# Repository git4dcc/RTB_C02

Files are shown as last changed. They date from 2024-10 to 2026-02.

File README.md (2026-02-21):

# RTB_C02



My C02 module is designed to trace DCC Railcom traffic for decoder debugging and development purposes. In particular the Railcom capture is an important feature and helps to validate if a decoders is RCN-217 compliant. The C02 uses the Vt100 terminal emulation control codes for its user interface. Therefore a VT100 capeable terminal program is a must (e.g. putty, teraterm). The USB interface is galvanically isolated from the DCC track potential.

<details>
<summary>User Guides</summary>

- [User Guide - DE](https://rtb4dcc.de/DPM_User_Guide_de)<br>
- User Guide - EN

</details>

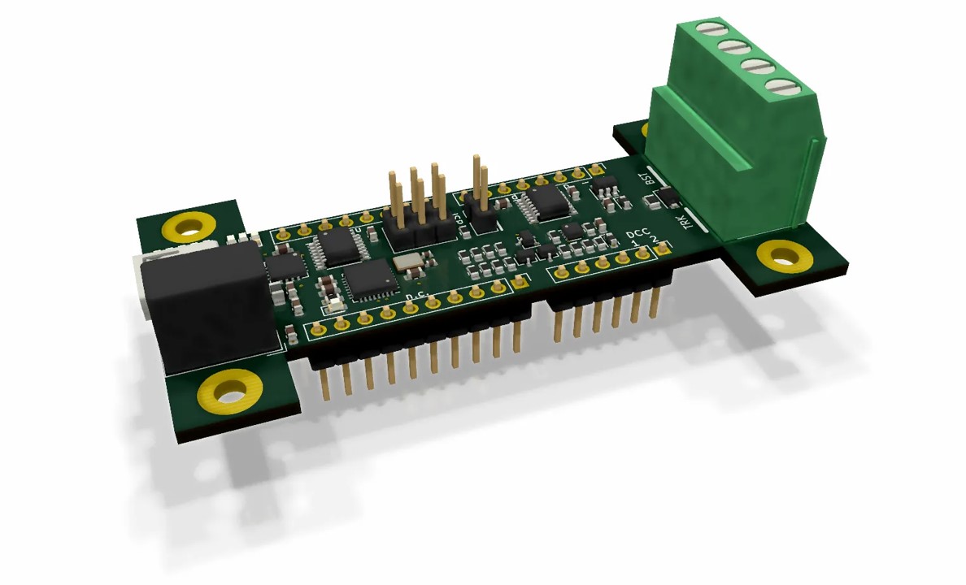
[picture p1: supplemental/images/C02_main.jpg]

<br>

# Hardware
My current PCB layout uses SMD footprints with 0.5mm pitch and mostly 0603 but some 0402 parts. Reflow soldering is my recommendation, but with some experience handsoldering may also be possible.

## PCB
- 4-layer PCB, FR4, 1.6mm
- CPU: mega328pb
- USB: FT232x (Mini-B)
- DC/DC: NME0505SC (or compatible)

## Kicad
[Schematic](doc/C02_schematic.pdf) | [Layout](doc/C02_layout.pdf) | [Gerber](gerber/)

<details>
<summary>Dependency</summary>
<br>
  
:yellow_circle: Requires my Kicad project library [RTB_SamacSys](/../../../../git4dcc/RTB_SamacSys) in the same directory tree.

</details>

## Firmware
Filename structure: { **pcb** }{ **code** }{ **version** }.hex

Example: **C02F0001**.hex

| | Description |
| --- | --- |
| **pcb** | Name of matching hardware (**C02**) |
| **code** | Type of code contained (**R**=rom, **B**=bootloader, **F**=flash, **U**=bld update, **P**=UPDI/SPI factory code) |
| **version** | Release version (**####**) |

## ISP
The fuse settings as well as the P-code (C02Pxxxx.hex) has to be installed by using the ISP.<br>

<details>
<summary>Details</summary>
<br>

> **CAUTION:** Before connecting the ISP, the jumper next to the ISP 6-pin interface must be closed (yellow jumper on picture).

<br>
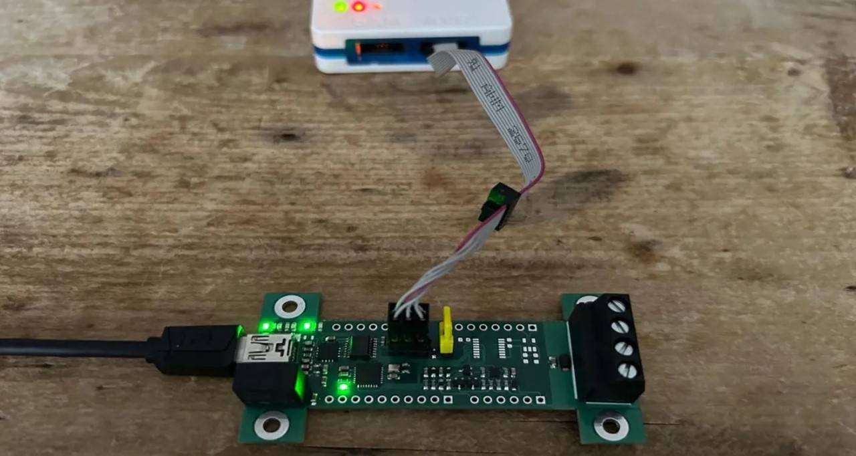
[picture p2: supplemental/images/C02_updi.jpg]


| Fuses Setting | Bootloader Install |
| --- | --- |
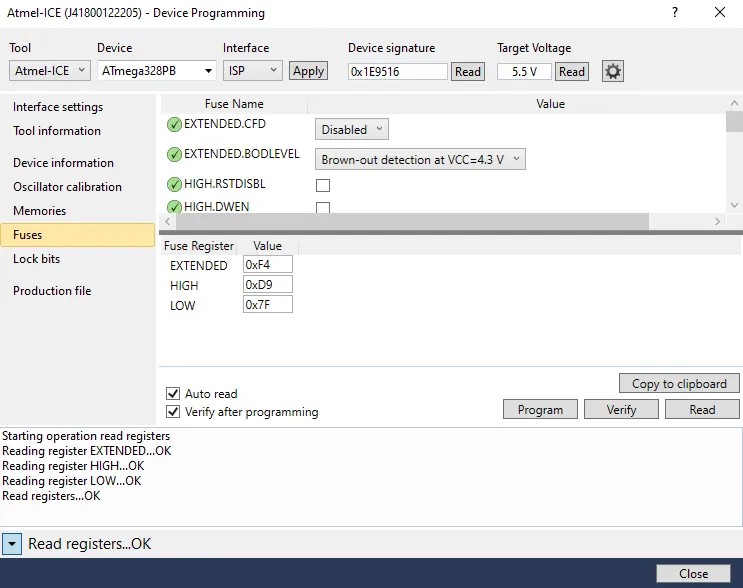
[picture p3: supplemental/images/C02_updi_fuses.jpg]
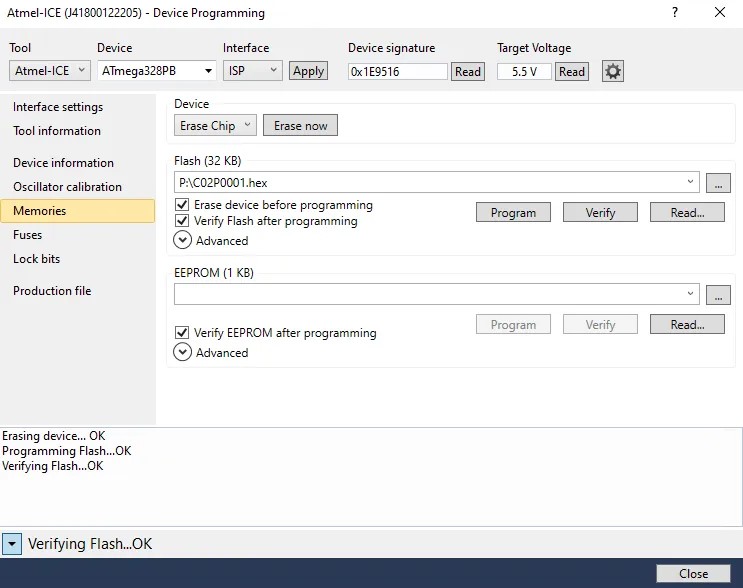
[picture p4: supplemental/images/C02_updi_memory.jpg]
|||

</details>

## Bootloader
Subsequent main code updates can be done via uploading the new firmware (C02Fxxxx.hex) file to the bootloader console prompt.<br>

<details>
<summary>Details</summary>

- press F1 to switch to console screen
- press ^b (ctrl-b) to enter bootloader
- upload the firmware file (C02Fxxxx.hex)
- press x to exit the bootloader

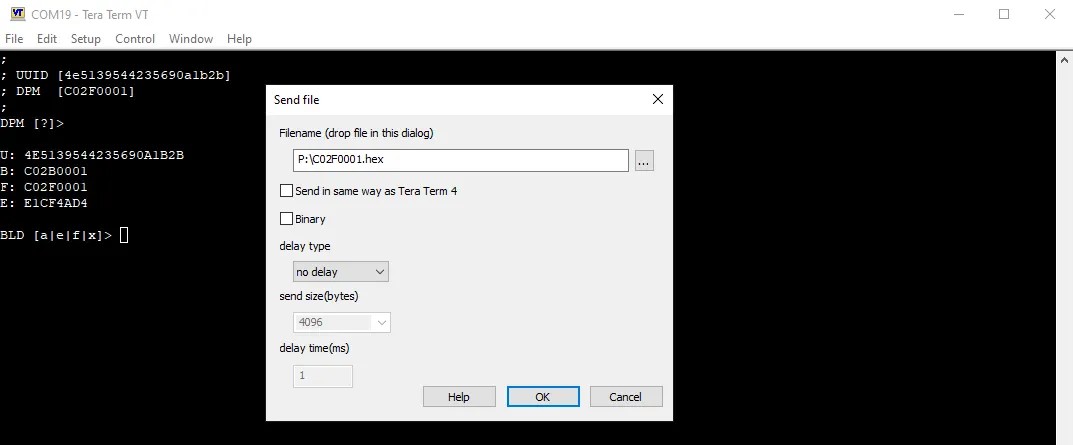
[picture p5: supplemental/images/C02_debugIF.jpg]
  

</details>

# Software
Operating the C02 is within the terminal window.
## Terminal screens
Below some example screens of the different functional sections. The screens (called aspects) can be switched by pressing F1-F7.
All screens are updated in real-time speed, ensuring always up-to-date information shown.

| Aspect | Example |
| --- | --- |
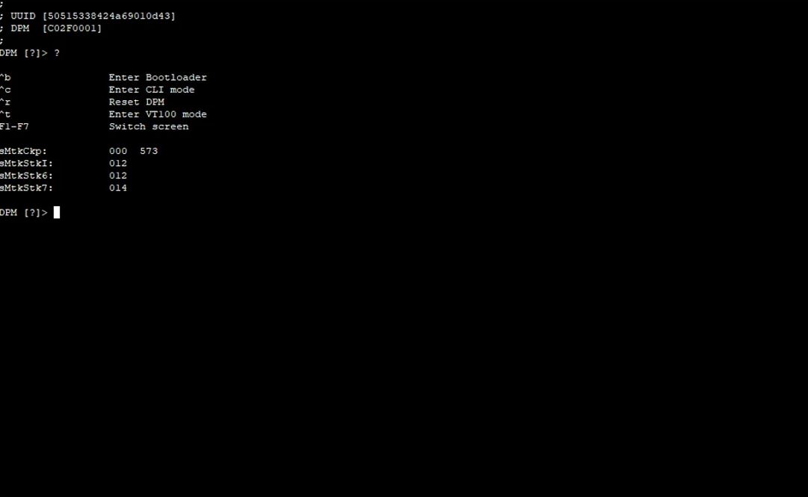
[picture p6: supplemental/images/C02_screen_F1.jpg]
| **F1:** Console prompt. |  |
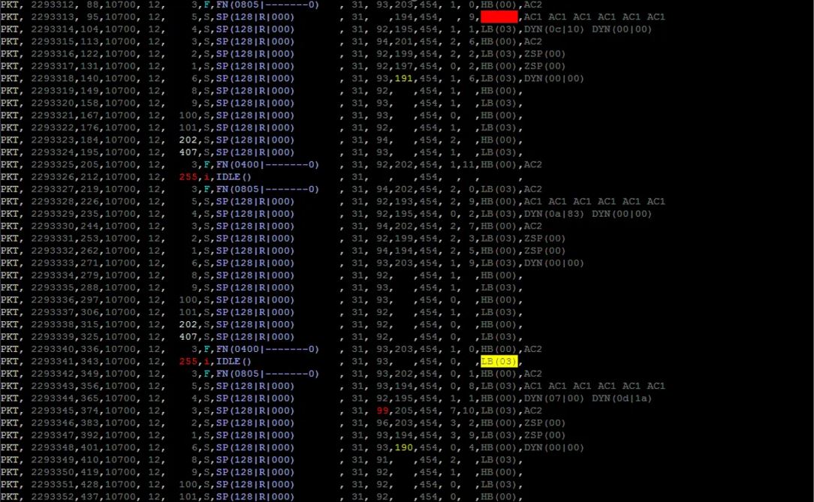
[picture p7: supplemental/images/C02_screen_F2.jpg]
| **F2:** DCC/Railcom line by line real-time trace. |  |
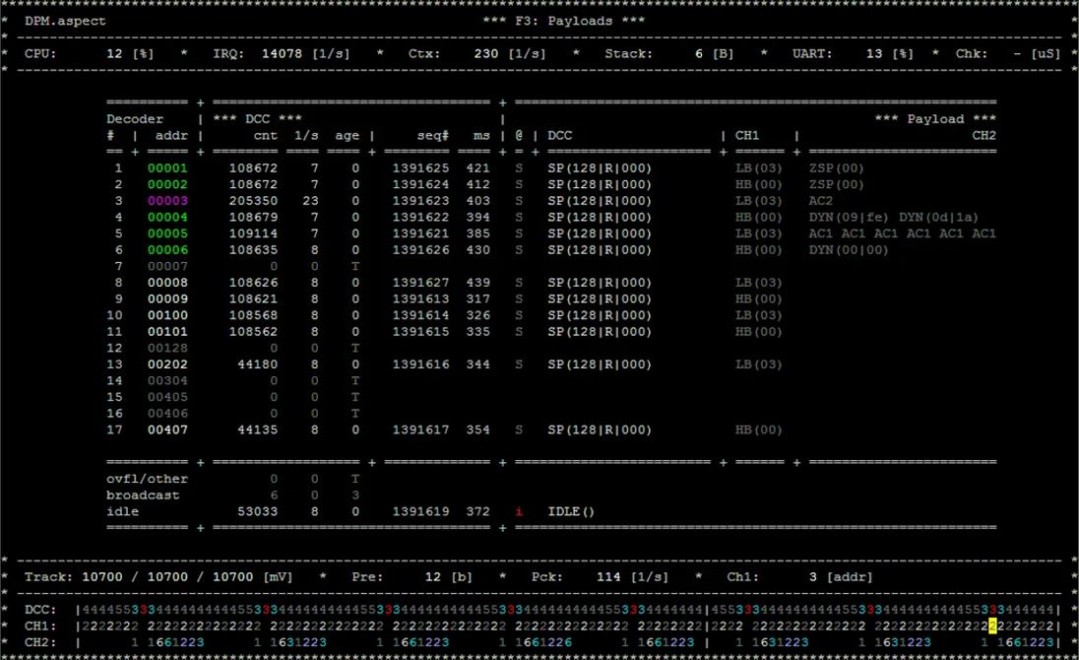
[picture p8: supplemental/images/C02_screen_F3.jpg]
| **F3:** DCC/Railcom decoder payload |  |
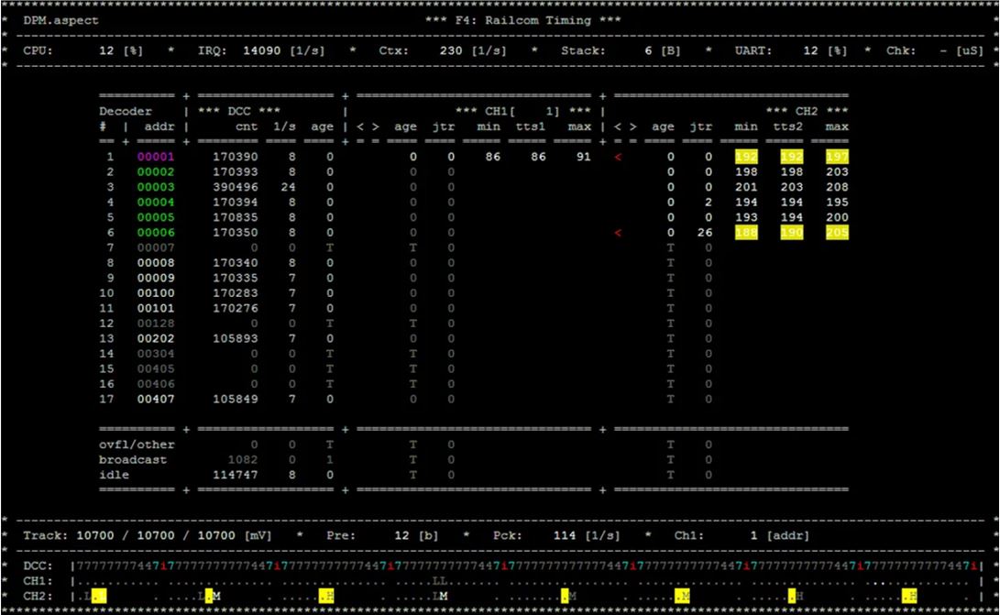
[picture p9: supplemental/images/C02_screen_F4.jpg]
| **F4:** DCC/Railcom timing<br> |  |
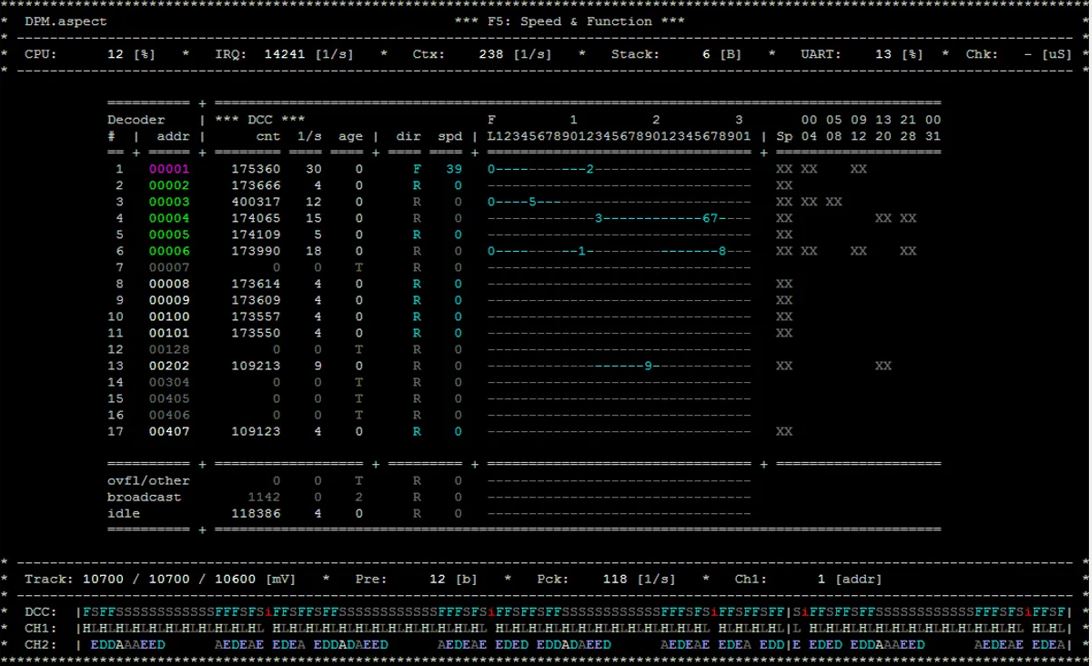
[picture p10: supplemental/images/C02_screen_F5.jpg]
| **F5:** DCC command set |  |
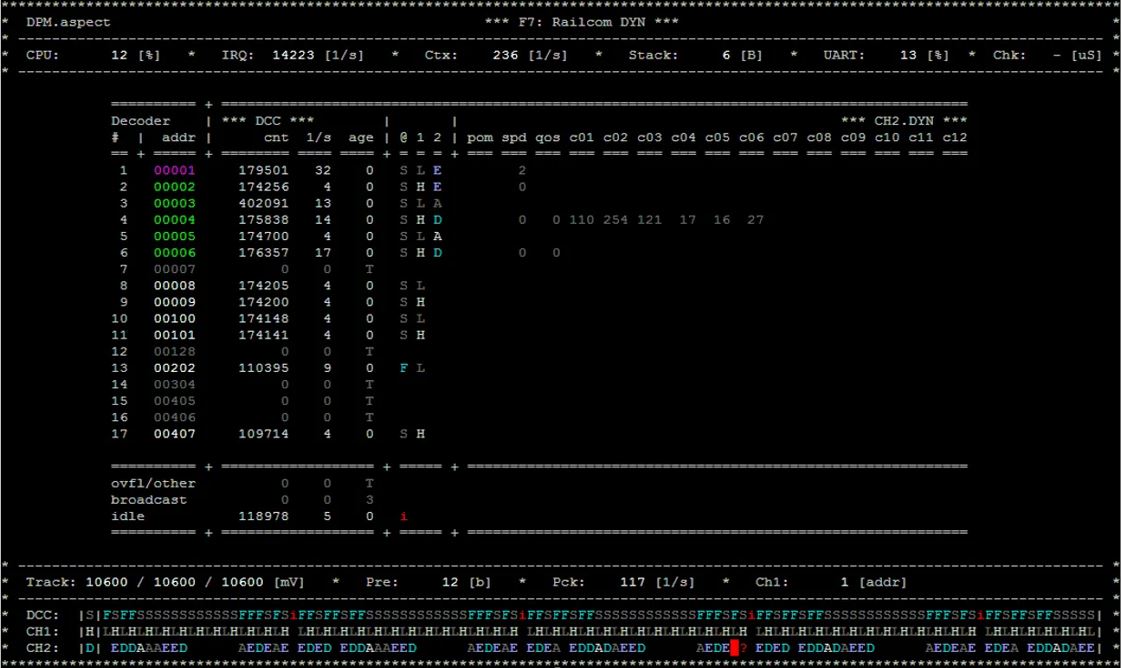
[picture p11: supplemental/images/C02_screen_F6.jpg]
| **F6:** Railcom response set |  |

# Images
This is how the PCB looks like.<br><br>
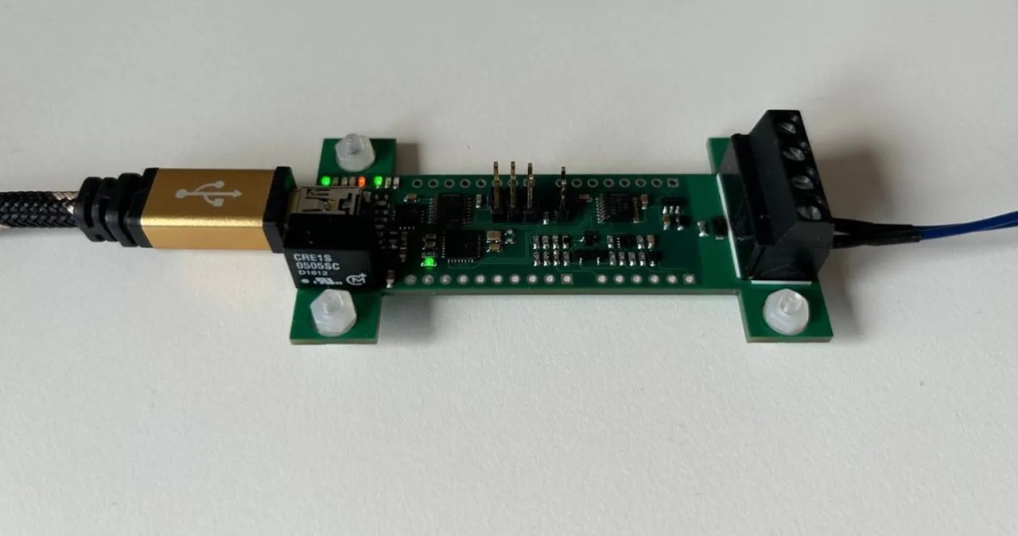
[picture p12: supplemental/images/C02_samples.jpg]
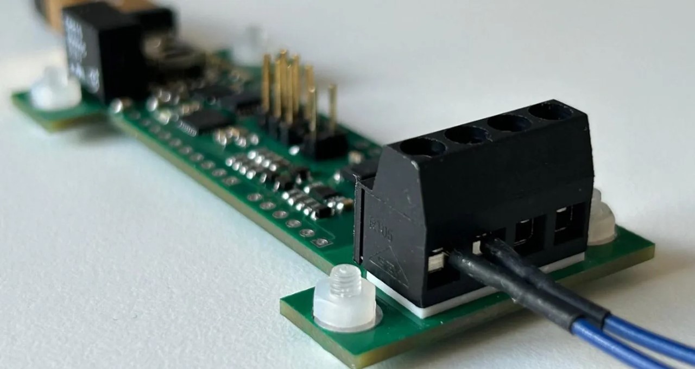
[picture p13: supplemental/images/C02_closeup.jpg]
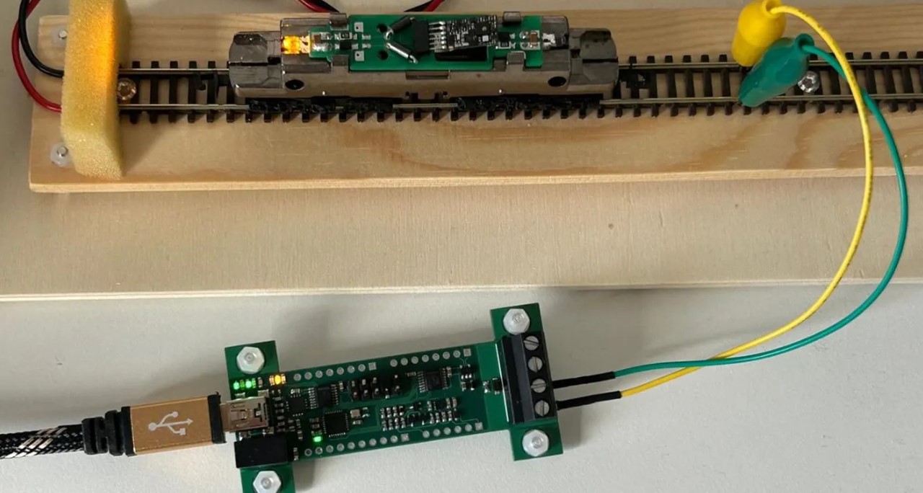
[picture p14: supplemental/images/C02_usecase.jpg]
    

# YouTube
Some short videos to see the DCC/Railcom logger in action.<br><br>
[](https://youtu.be/7zXp4IKSk08)  [](https://youtu.be/JmhkPcqBb-c)

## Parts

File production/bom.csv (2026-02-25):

Designator | Footprint | Quantity | Value | LCSC Part #
C1, C10, C16, C17, C18, C19, C9 | 0603 | 7 | 1u | C15849
C11, C22, C5, C7 | 0603 | 4 | 100n | C14663
C12, C13 | 0402 | 2 | 8p | C32949
C14, C15 | 0603 | 2 | 47p | C1671
C2, C6, C8 | 0603 | 3 | 10u/25V | C96446
D1 | 0603 | 1 | D_Schottky
D10, D19 | D_SMA | 2 | SSA33L | C435944
D11, D12, D8 | 0603 | 3 | LED_grn | C2289
D13 | 0603 | 1 | Hbt(grn) | C2289
D14 | 0603 | 1 | INF(ylw) | C2287
D15 | 0603 | 1 | ACK(blu) | C2288
D16 | 0603 | 1 | LED(grn) | C2289
D17, D18 | 0603 | 2 | LED_red | C125099
D2 | 0603 | 1 | D_Schottky | C143804
D3, D4 | SOT-323_SC-70 | 2 | BAT54S | C78606
D5 | SOT-323_SC-70 | 1 | BAT54A | C78261
J1 | USB_Micro-B_Reichelt_BWM_SMD | 1 | USB_B_Mini | C2688795
J10, J7, J8, J9 | MountingHole_3.2mm_M3_Pad | 4 | Conn_01x01
J11 | PinHeader_2x03_P2.54mm_Vertical | 1 | ISP
J12 | PinHeader_1x02_P2.54mm_Vertical | 1 | Conn_01x02
J2 | PinHeader_1x10_P2.54mm_Vertical | 1 | Conn_01x10_Male
J3 | PinHeader_1x06_P2.54mm_Vertical | 1 | Conn_01x06_Male
J4, J5 | PinHeader_1x08_P2.54mm_Vertical | 2 | Conn_01x08_Male
J6 | TerminalBlock_RND_205-00003_1x04_P5.00mm_Horizontal | 1 | Screw_Terminal_01x04
L1 | 0805 | 1 | Ferrite_Bead | C1017
R1 | 0805 | 1 | 220 | C17557
R10, R12, R33, R7 | 0603 | 4 | 100k | C25803
R11, R9 | 0603 | 2 | 33k | C4216
R13 | 0603 | 1 | 220k | C22961
R14, R32 | 0603 | 2 | 10k | C25804
R15, R22, R23, R24, R25, R26, R28, R29, R30, R31 | 0603 | 10 | 4.7k | C23162
R16, R20 | 0603 | 2 | 27 | C23345
R19 | 0603 | 1 | 3.3k | C22978
R21 | 0603 | 1 | 10 | C22859
R4, R5, R6, R8 | 0603 | 4 | 1k | C21190
RN1 | R_Array_Concave_4x0603 | 1 | 4.7k | C66697
U1 | QFN-32-1EP_5x5mm_P0.5mm_EP3.1x3.1mm | 1 | ATmega328PB-MU | C967933
U2 | DCDC-Conv_muRata_NMAxxxxSC | 1 | NME0505SC
U3 | SOT-23-5 | 1 | MIC5235-5.0 | C7202996
U4 | DFN-8_2x2mm_P0.5mm | 1 | LM393 | C2970927
U6 | QFN-16-1EP_4x4mm_P0.65mm_EP2.5x2.5mm | 1 | FT230XQ | C3216402
U7 | SSOP-16_3.9x4.9mm_P0.635mm | 1 | ISO7742 | C5216468
Y1 | Crystal_SMD_2016-4Pin_2.0x1.6mm | 1 | 16Mhz, 6pF | C1986052

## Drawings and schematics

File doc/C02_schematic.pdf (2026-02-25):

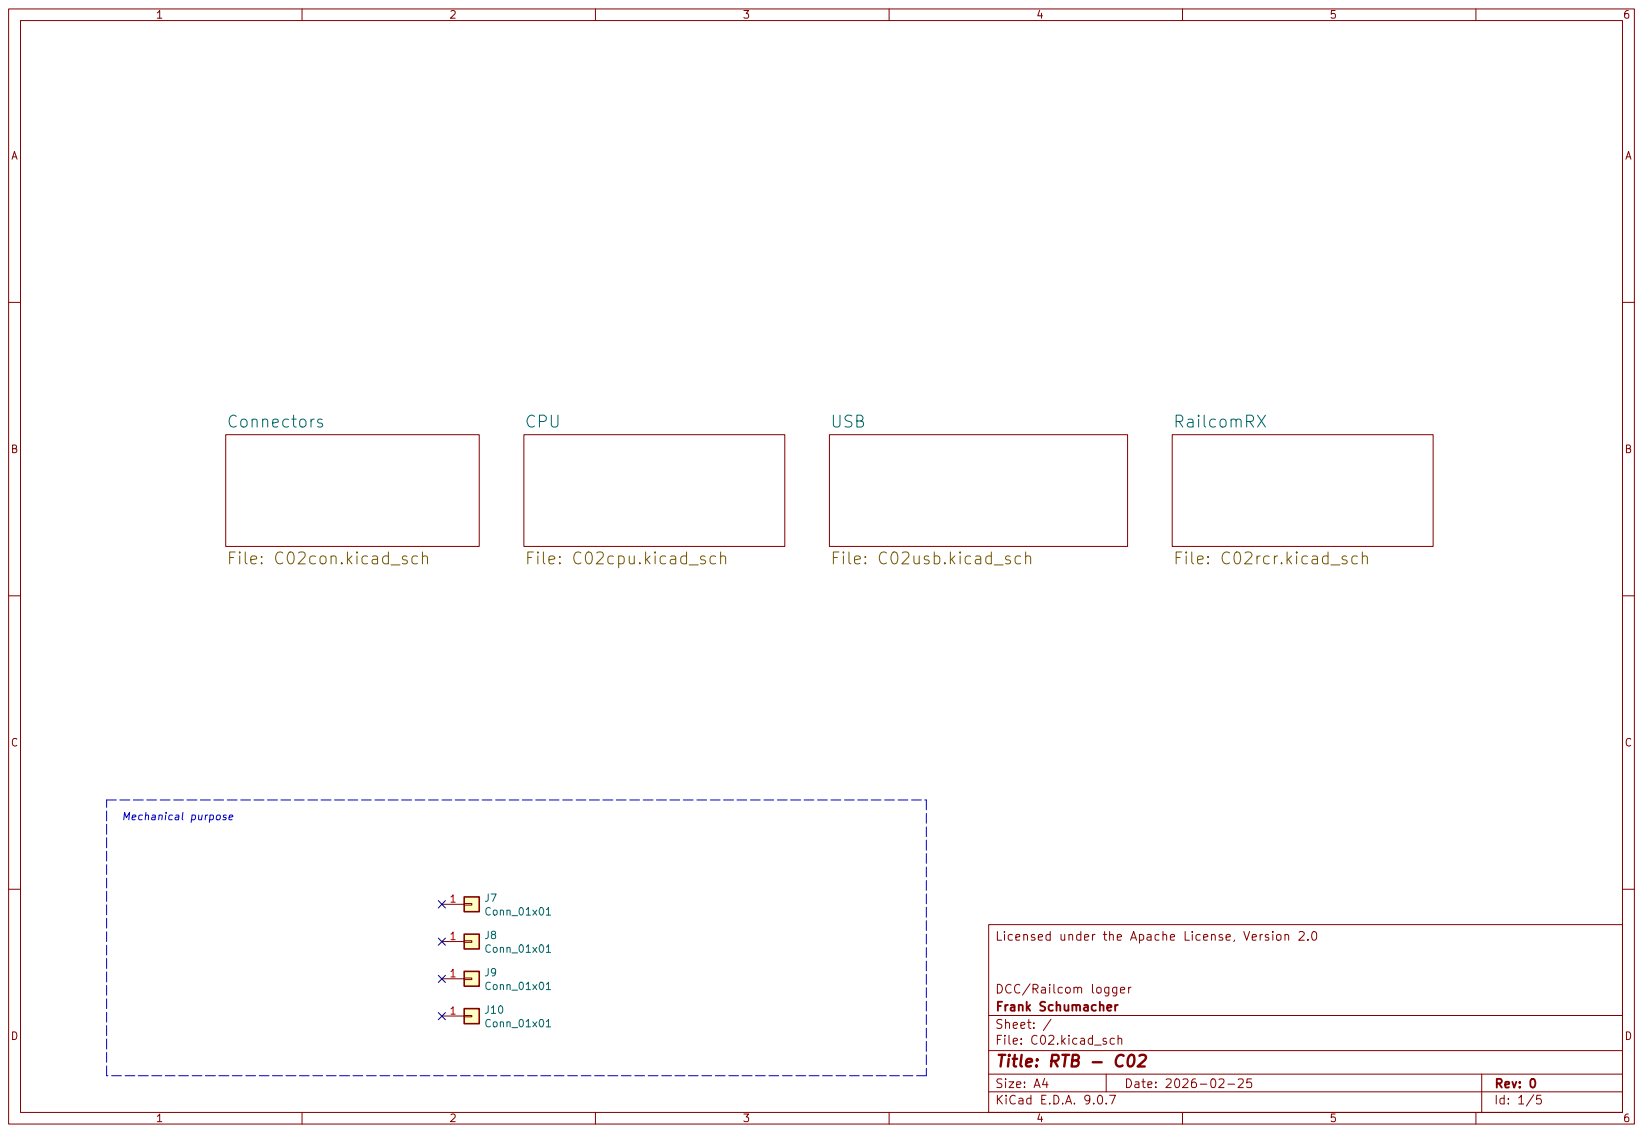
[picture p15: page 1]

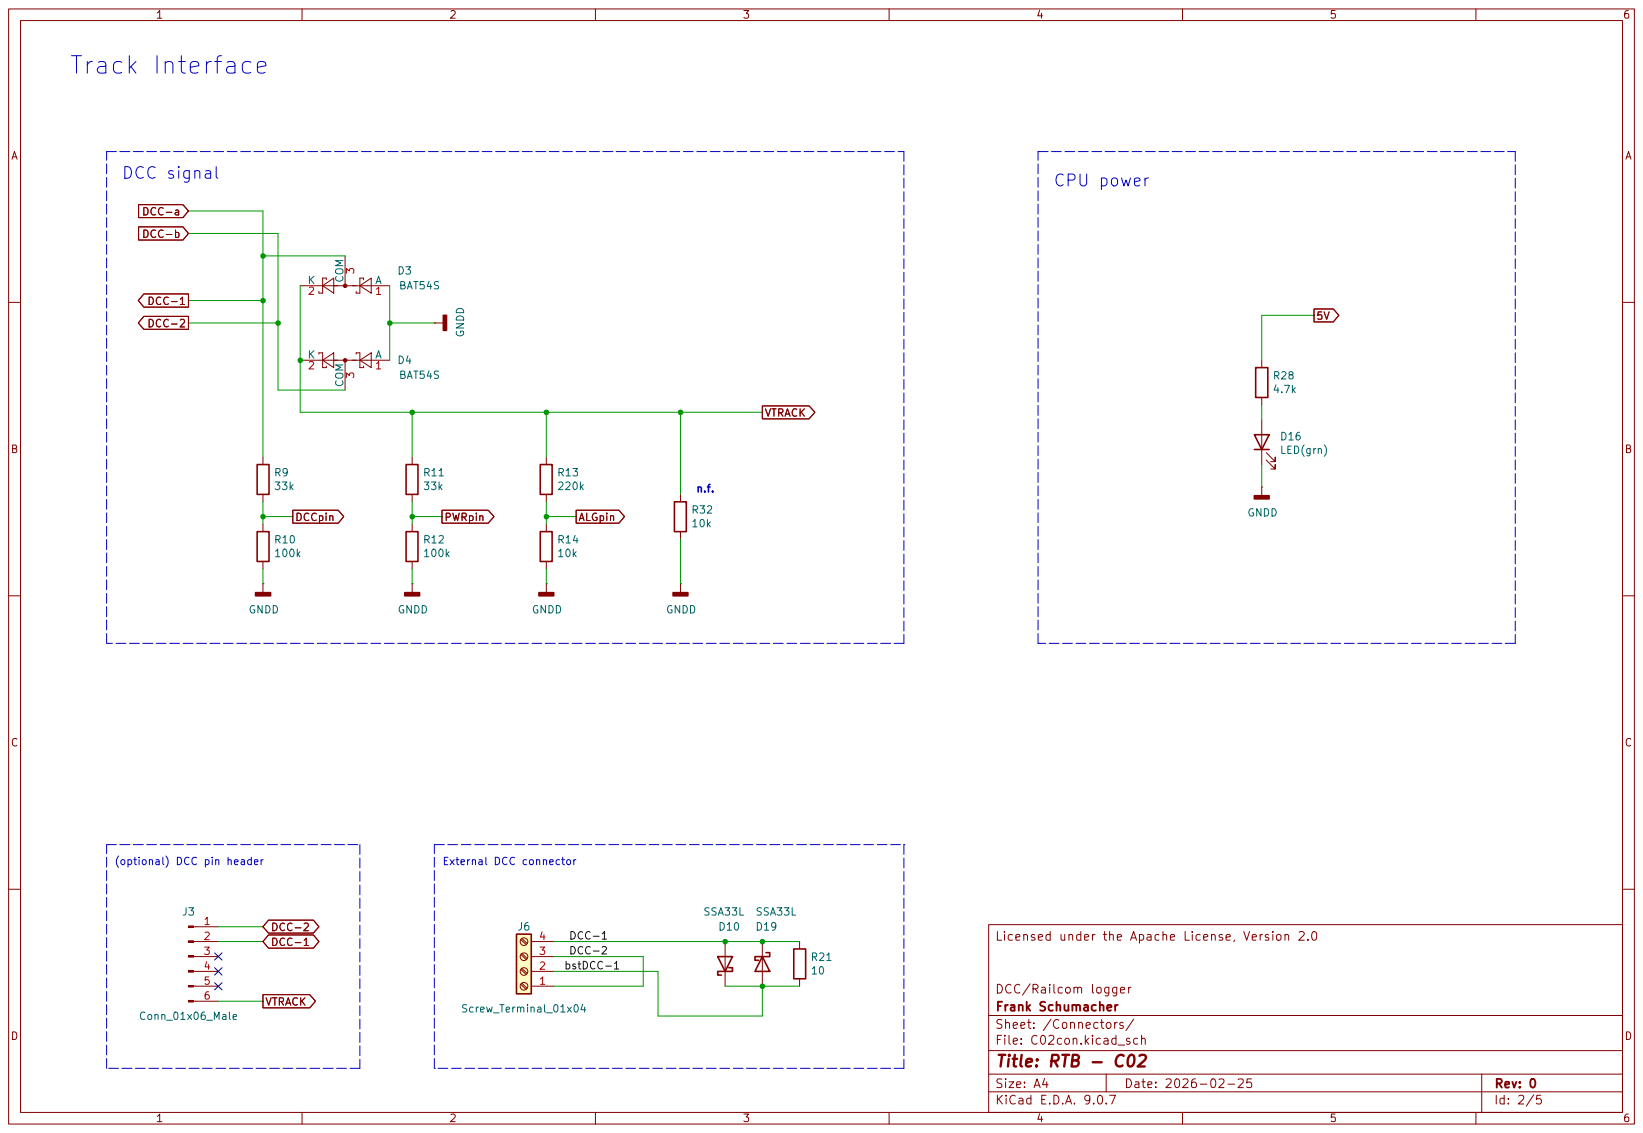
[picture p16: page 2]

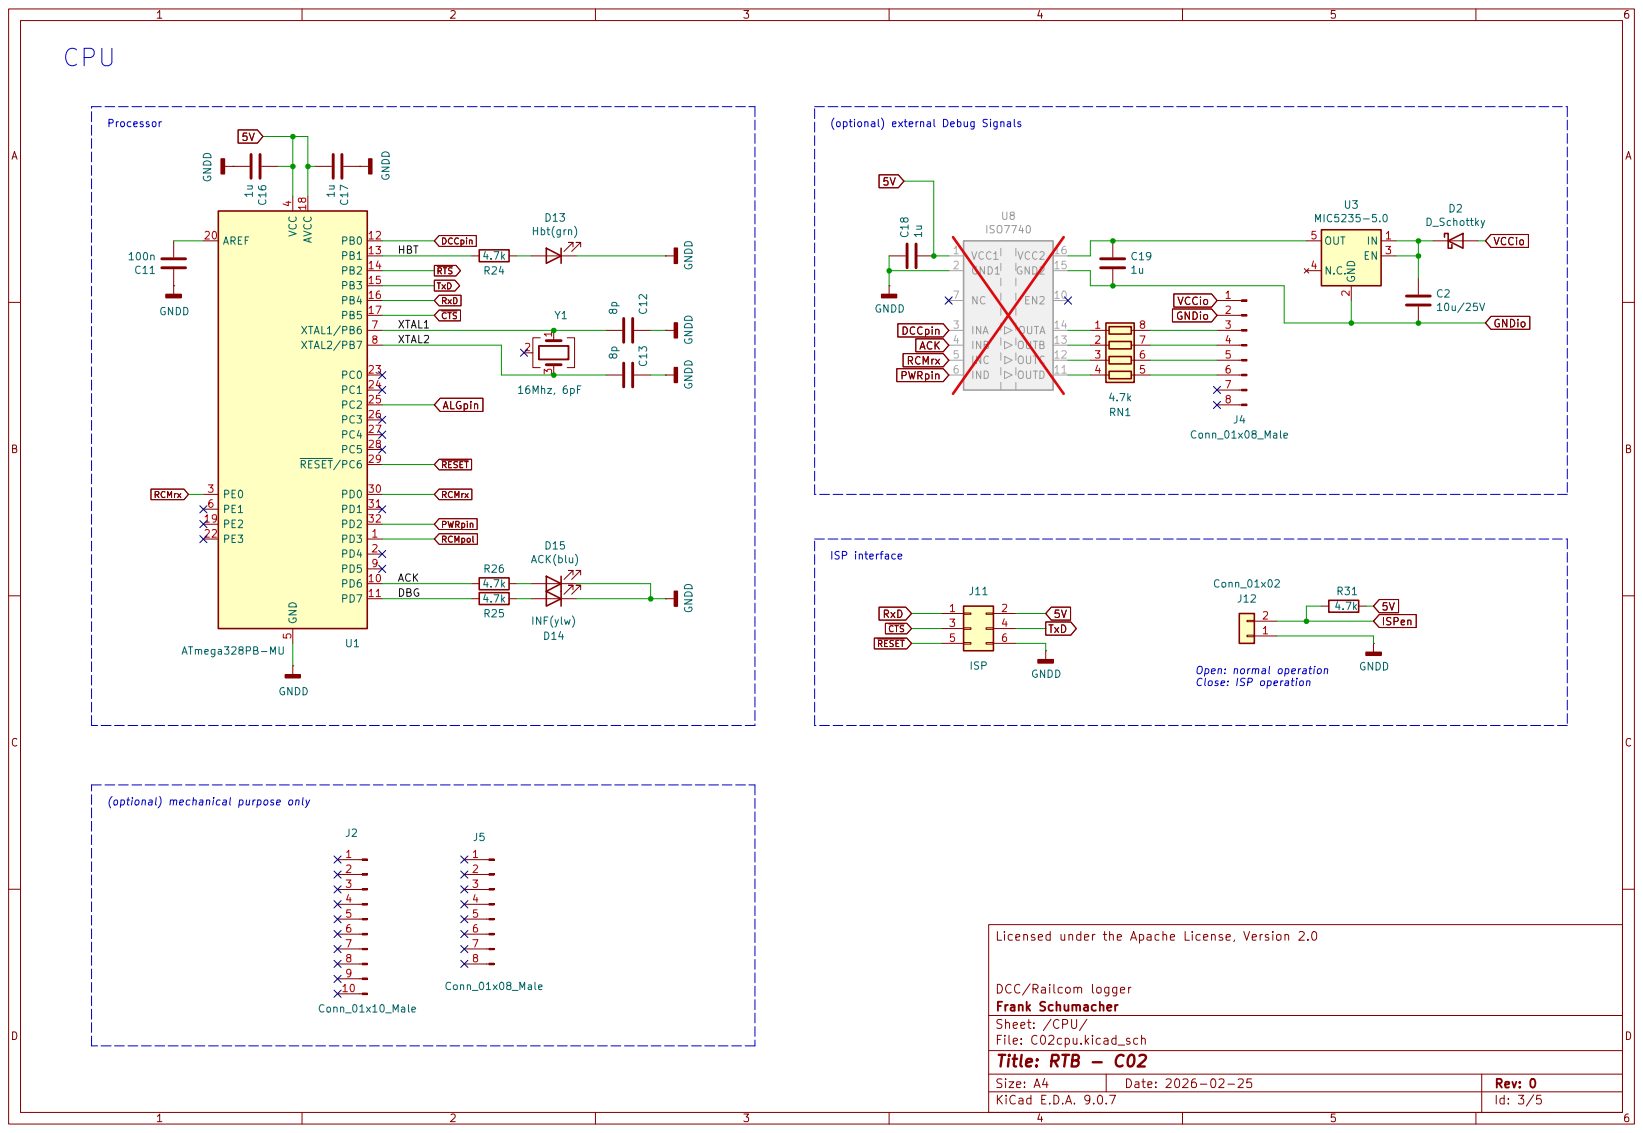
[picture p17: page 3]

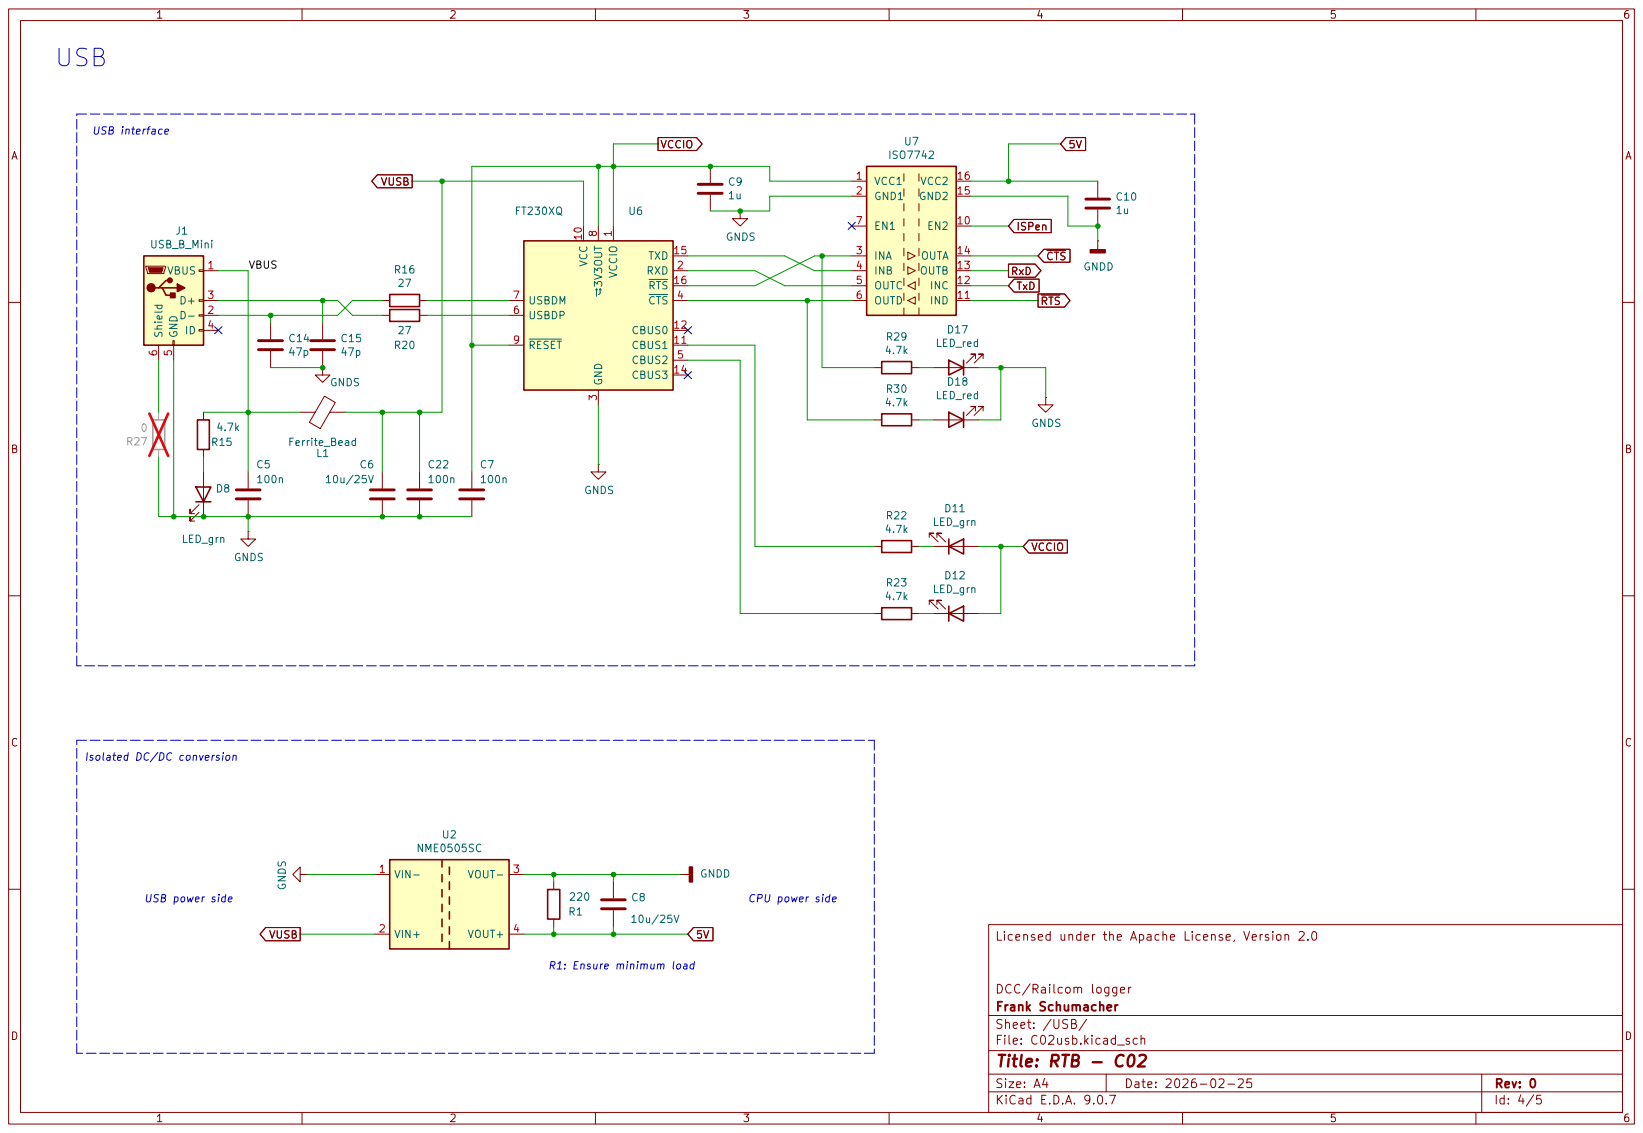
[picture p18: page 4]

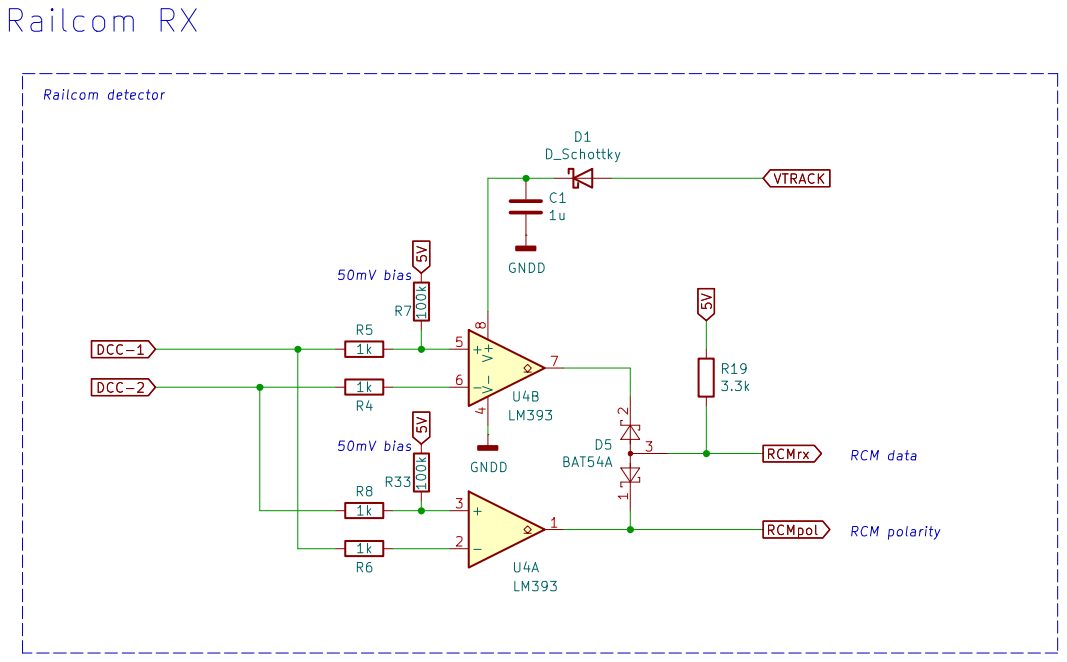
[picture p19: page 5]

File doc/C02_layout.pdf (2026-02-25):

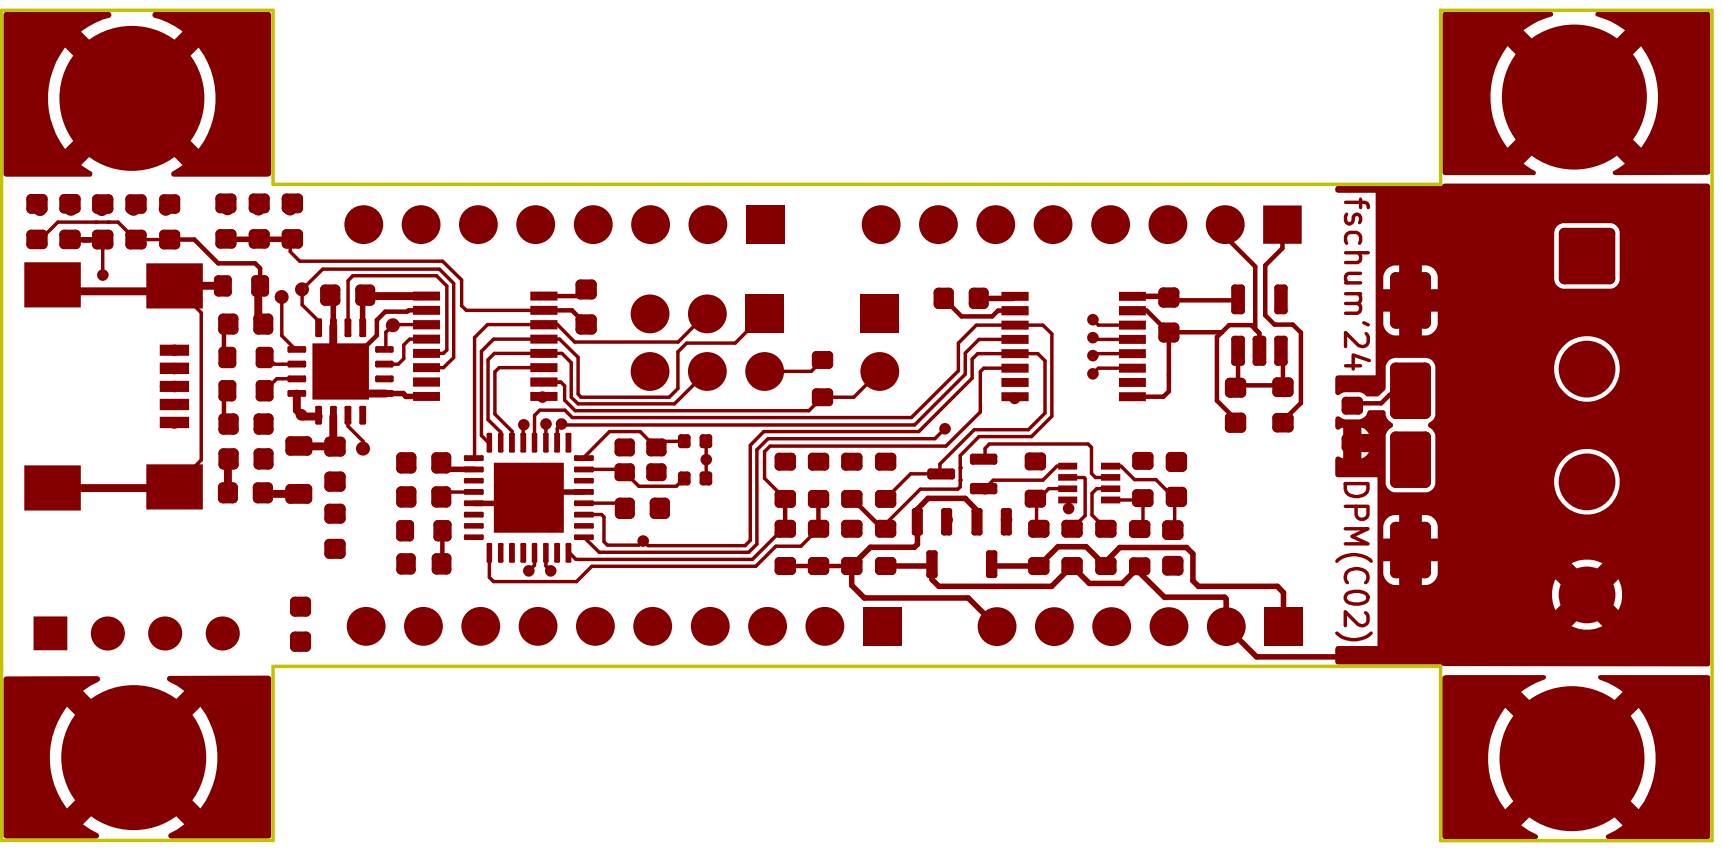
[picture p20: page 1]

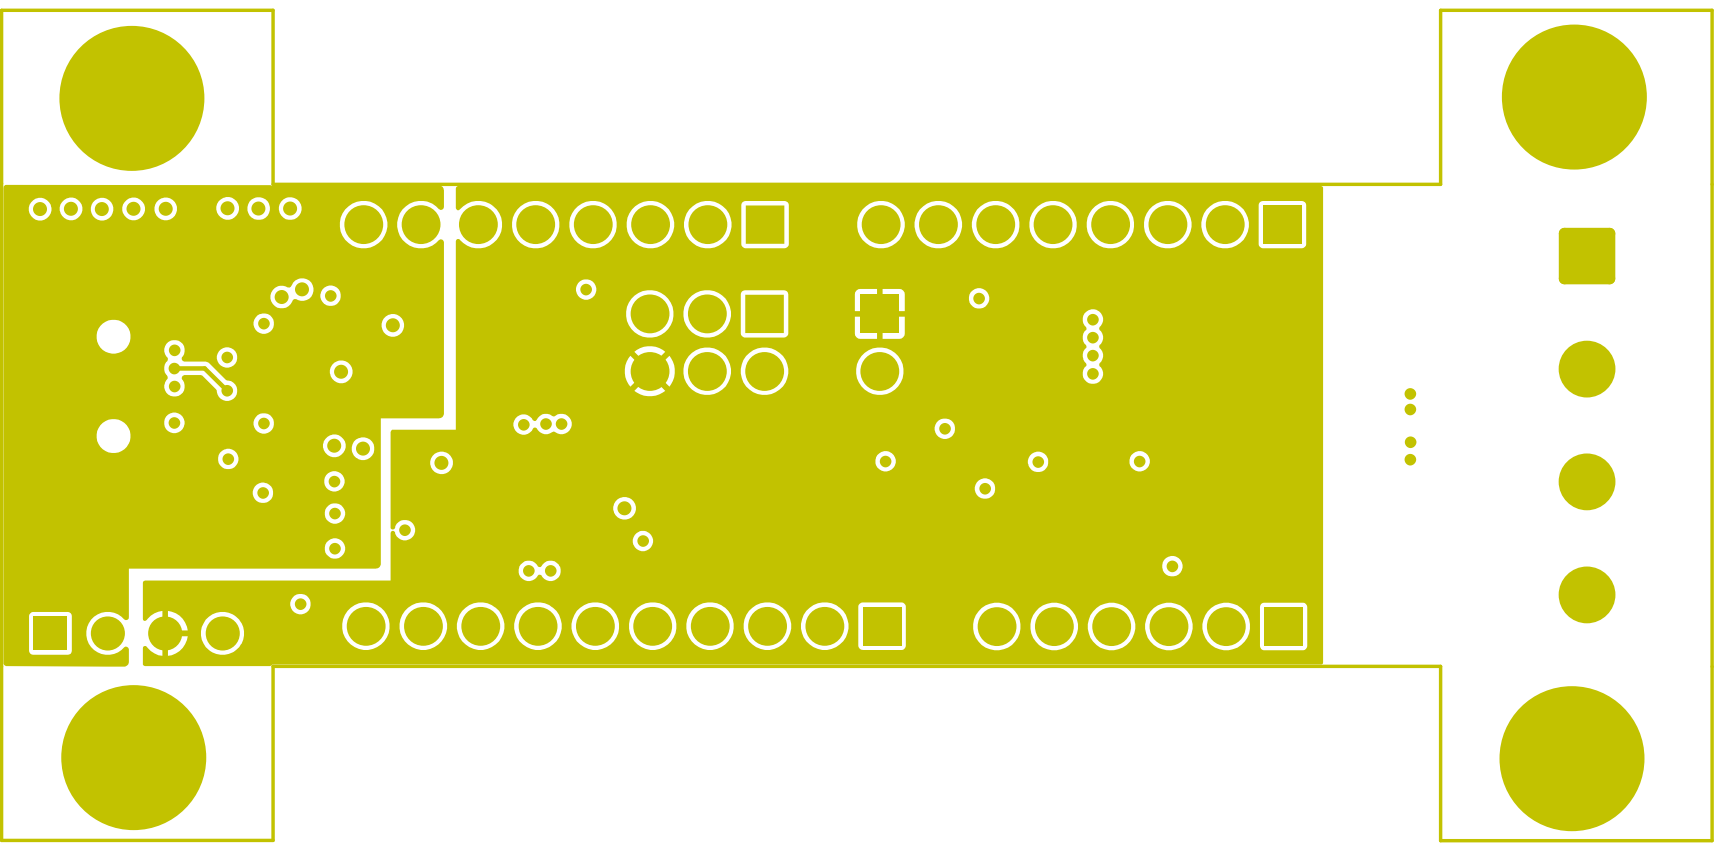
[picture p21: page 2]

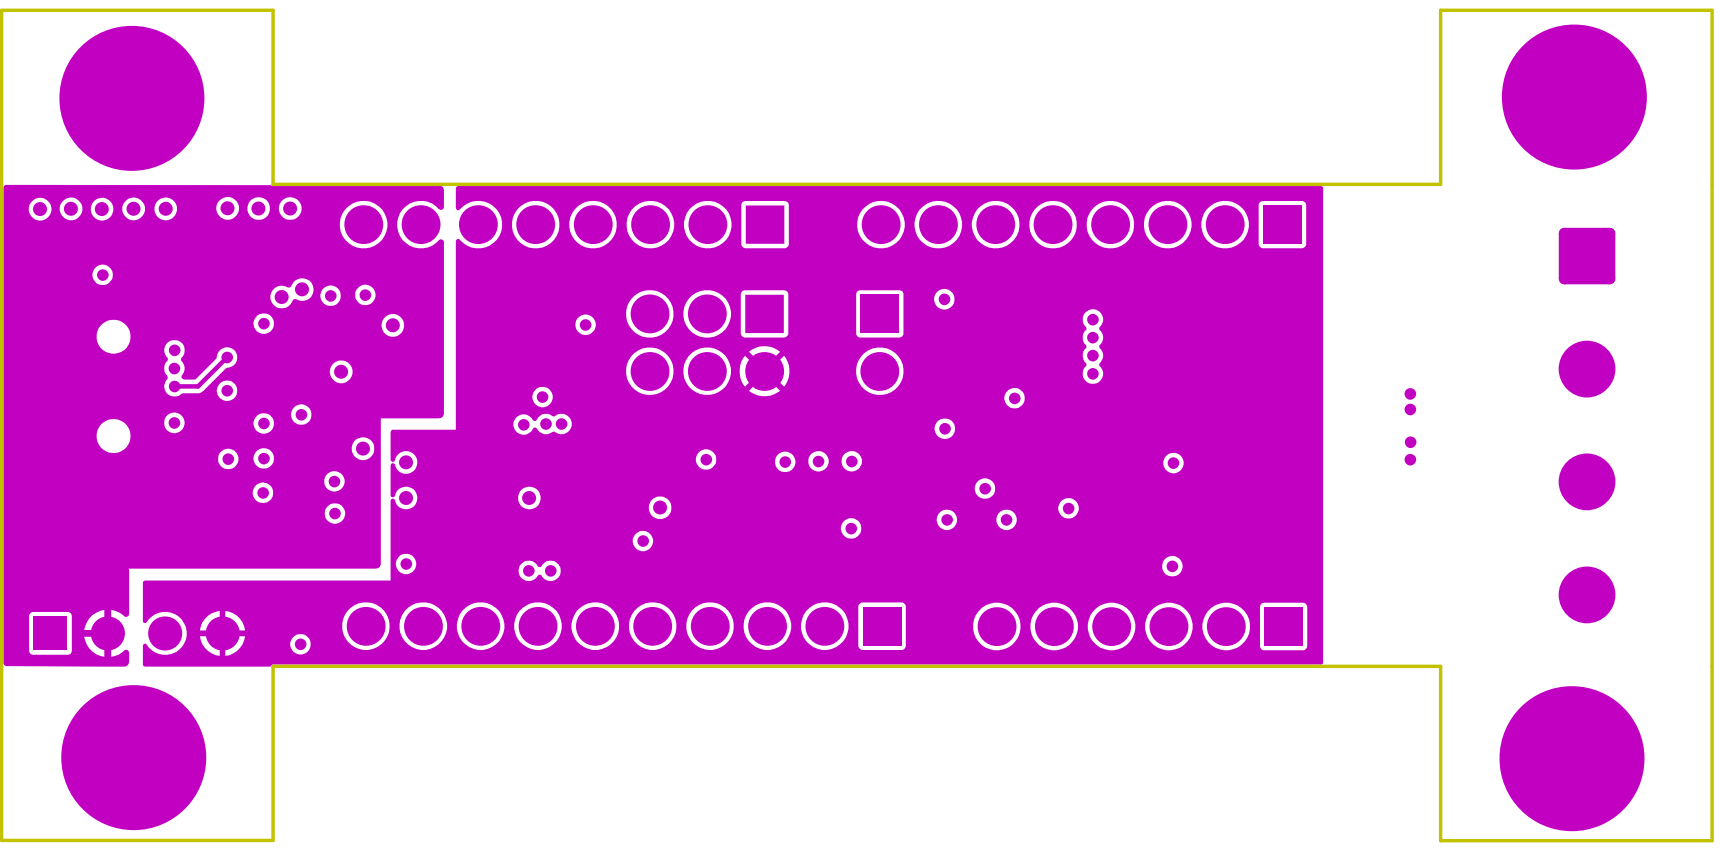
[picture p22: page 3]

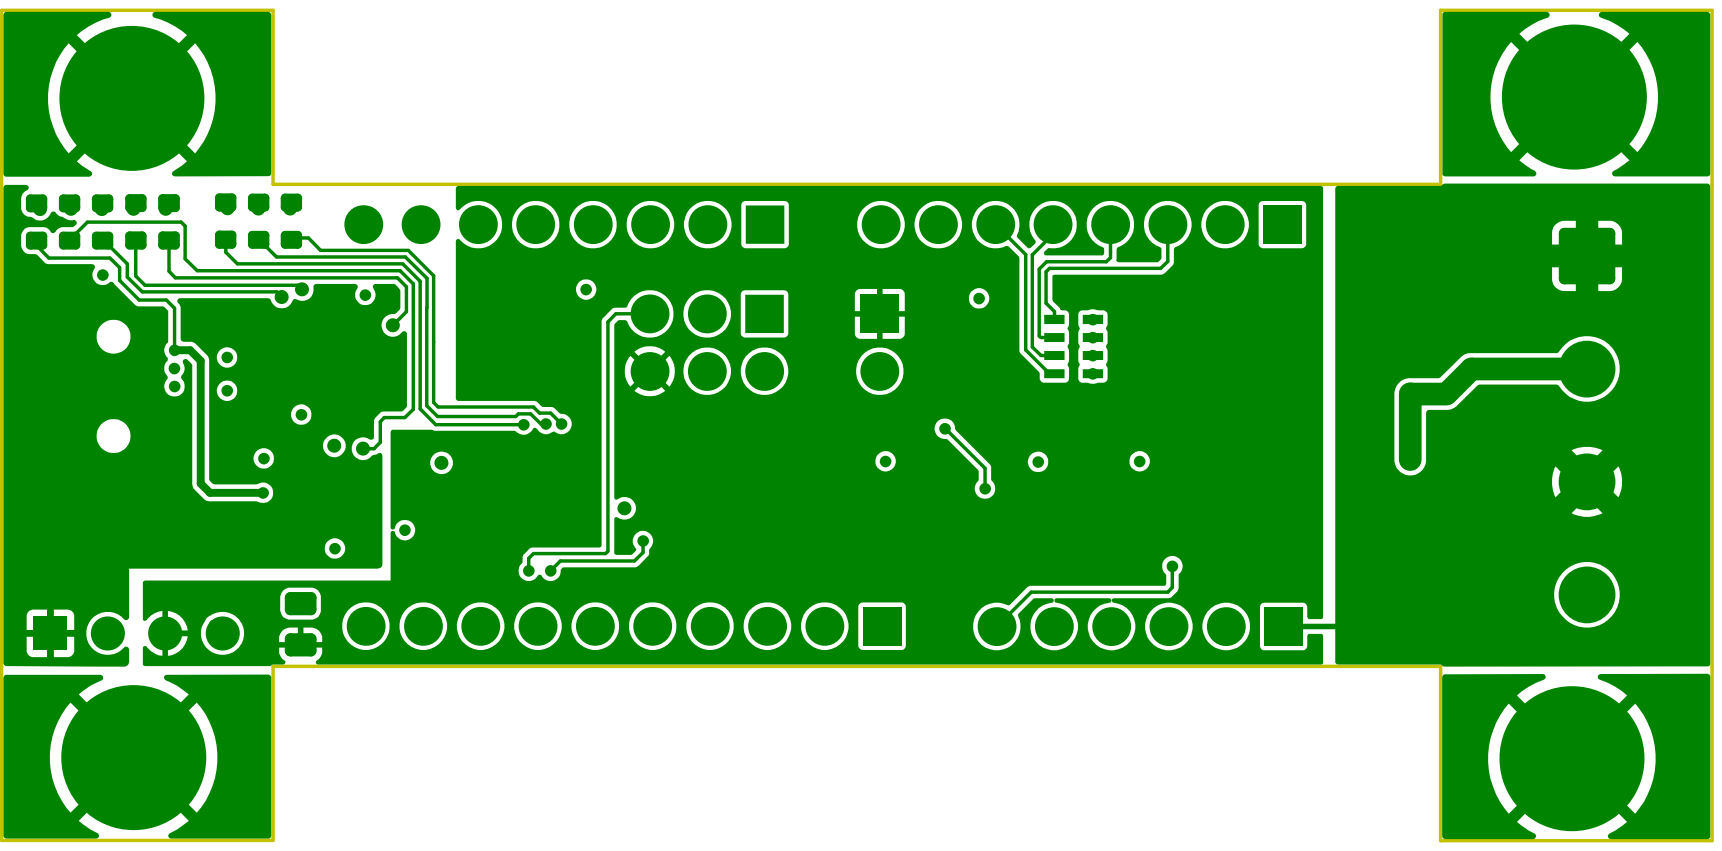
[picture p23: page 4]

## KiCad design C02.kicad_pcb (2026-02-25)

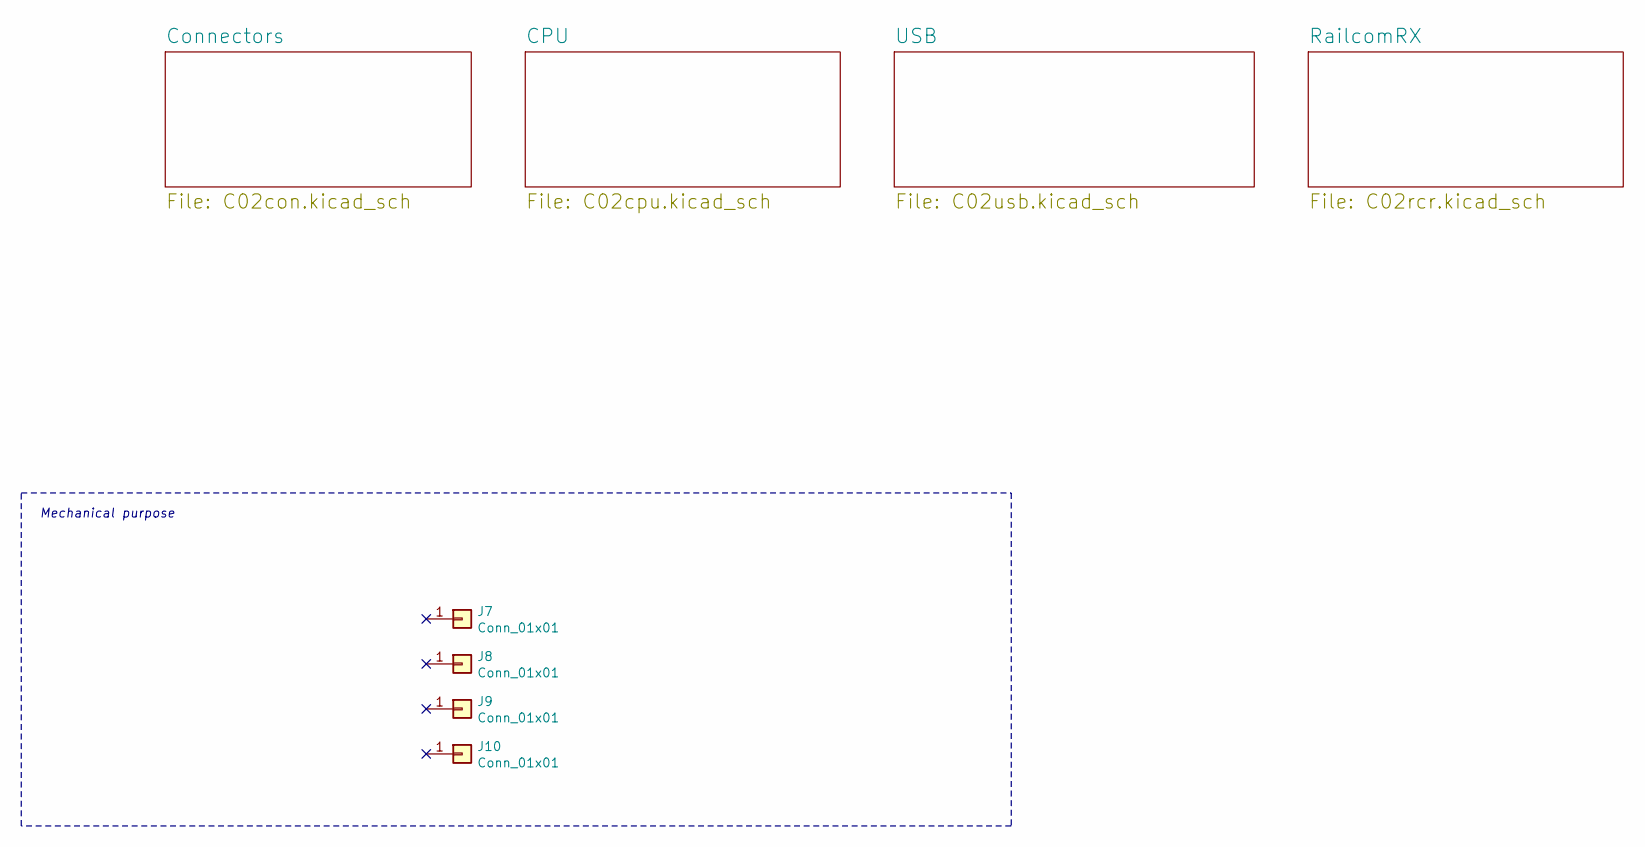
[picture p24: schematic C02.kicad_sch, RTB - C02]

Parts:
J7, J8, J9, J10: Conn_01x01; MountingHole_3.2mm_M3_Pad

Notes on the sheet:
Mechanical purpose

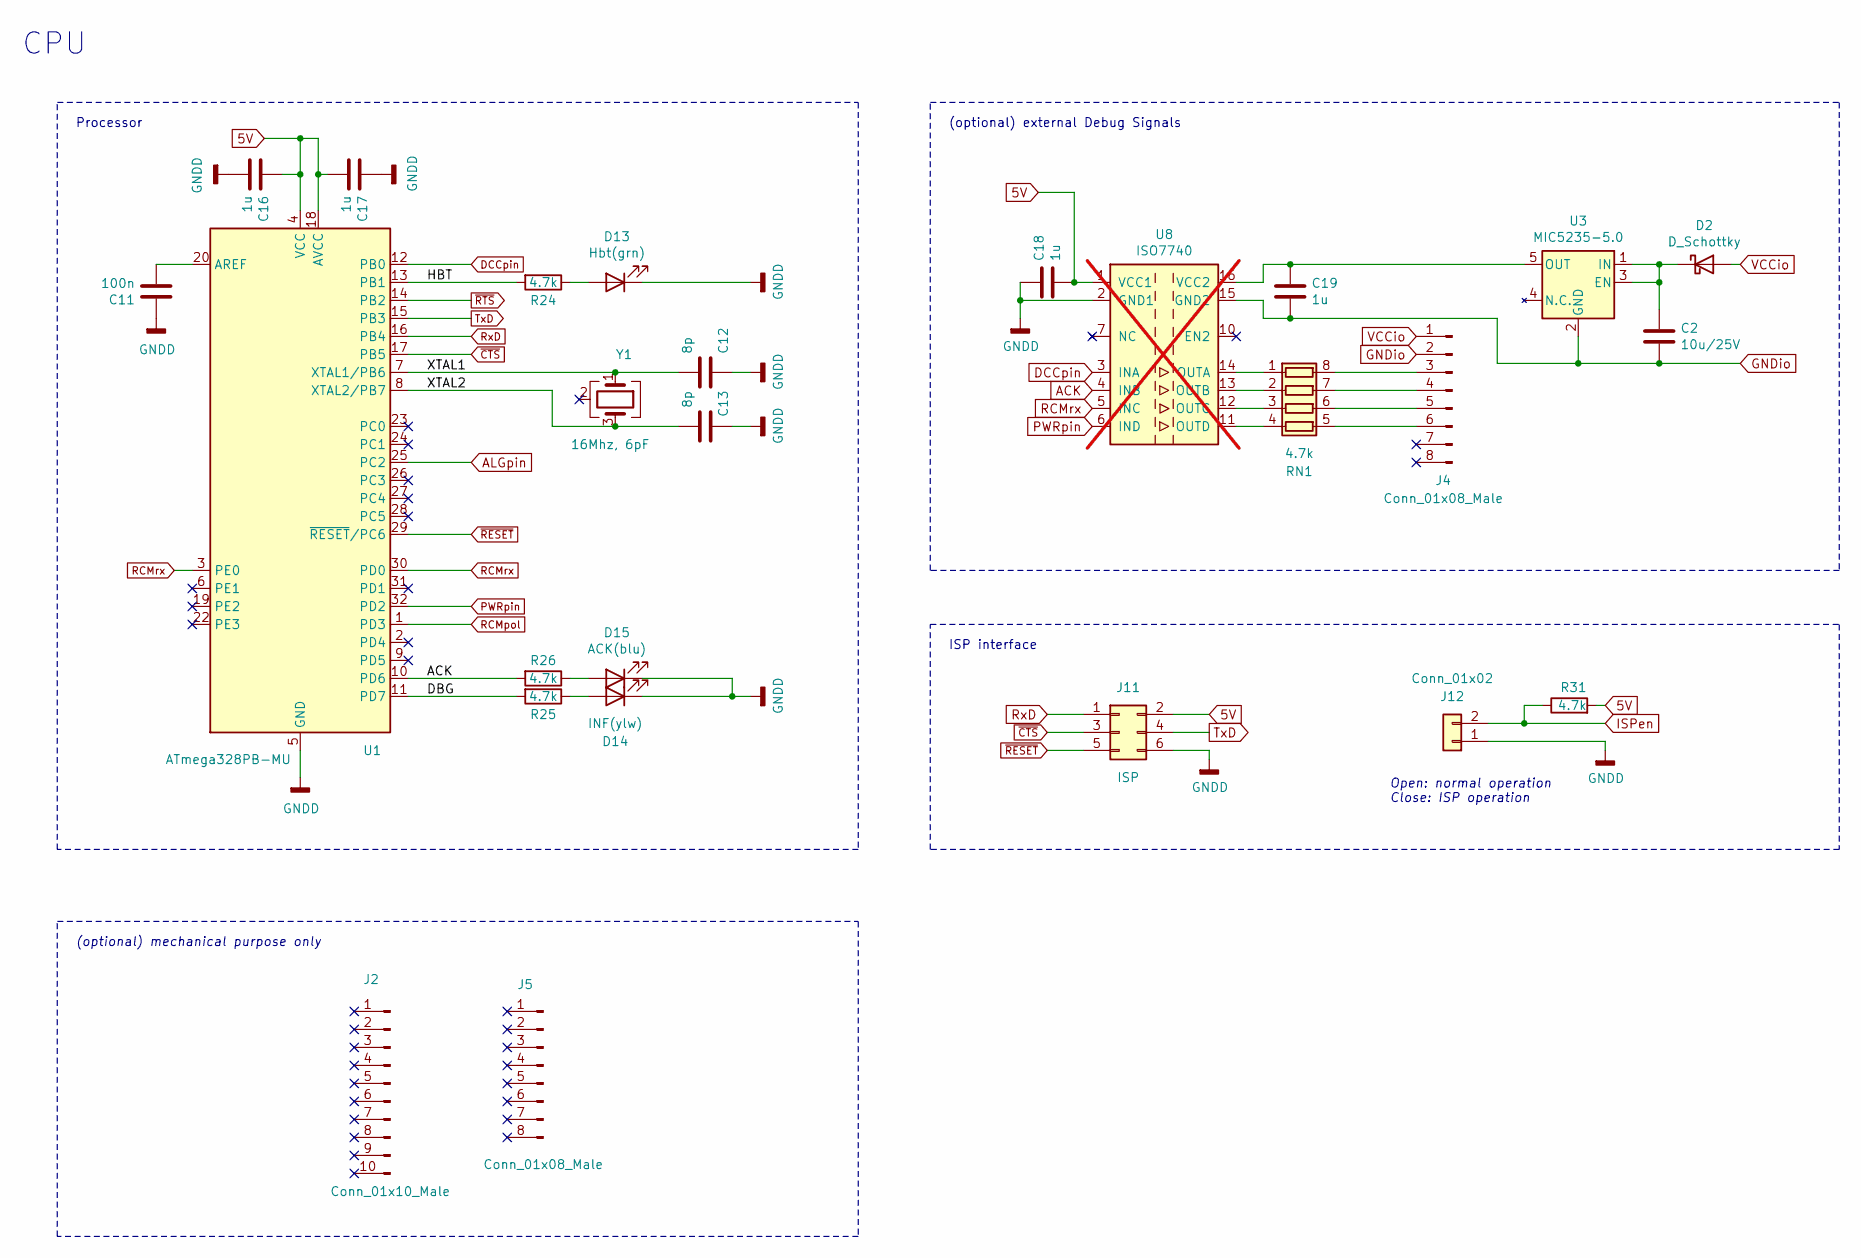
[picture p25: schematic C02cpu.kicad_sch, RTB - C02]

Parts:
C2: 10u/25V; C_0603_1608Metric; LCSC Part # C96446
C11: 100n; C_0603_1608Metric; LCSC Part # C14663
C12, C13: 8p; C_0402_1005Metric; LCSC Part # C32949
C16, C17, C18, C19: 1u; C_0603_1608Metric; LCSC Part # C15849
D2: D_Schottky; D_0603_1608Metric; LCSC Part # C143804
D13: Hbt(grn); LED_0603_1608Metric; LCSC Part # C2289
D14: INF(ylw); LED_0603_1608Metric; LCSC Part # C2287
D15: ACK(blu); LED_0603_1608Metric; LCSC Part # C2288
J2: Conn_01x10_Male; PinHeader_1x10_P2.54mm_Vertical
J4, J5: Conn_01x08_Male; PinHeader_1x08_P2.54mm_Vertical
J11: ISP; PinHeader_2x03_P2.54mm_Vertical
J12: Conn_01x02; PinHeader_1x02_P2.54mm_Vertical
R24, R25, R26, R31: 4.7k; R_0603_1608Metric; LCSC Part # C23162
RN1: 4.7k; R_Array_Concave_4x0603; LCSC Part # C66697
U1: ATmega328PB-MU; QFN-32-1EP_5x5mm_P0.5mm_EP3.1x3.1mm; LCSC Part # C967933
U3: MIC5235-5.0; SOT-23-5; LCSC Part # C7202996
U8: ISO7740; SSOP-16_3.9x4.9mm_P0.635mm; LCSC Part # C5216473; not fitted
Y1: 16Mhz, 6pF; Crystal_SMD_2016-4Pin_2.0x1.6mm; LCSC Part # C1986052

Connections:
5V: C16.2, C17.1, C18.1, J11.2, R31.2, U1.4 (VCC), U1.18 (AVCC), U8.1 (VCC1); also elsewhere on the board
/CPU/DBG: R25.2, U1.11 (PD7)
/CPU/HBT: R24.2, U1.13 (PB1)
/CPU/XTAL1: C12.2, U1.7 (XTAL1/PB6), Y1.1
/CPU/XTAL2: C13.2, U1.8 (XTAL2/PB7), Y1.3
ACK: R26.2, U1.10 (PD6), U8.4 (INB)
ALGpin: U1.25 (PC2); also elsewhere on the board
DCCpin: U1.12 (PB0), U8.3 (INA); also elsewhere on the board
GNDD: C11.2, C12.1, C13.1, C16.1, C17.2, C18.2, D13.1 (K), D14.1 (K), D15.1 (K), J11.6, J12.1, U1.5 (GND), U1.21 (GND), U1.33, U8.2 (GND1), U8.8 (GND1); also elsewhere on the board
GNDio: C2.1, C19.1, J4.2, U3.2 (GND), U8.9 (GND2), U8.15 (GND2)
ISPen: J12.2, R31.1; also elsewhere on the board
unnamed: C2.2, D2.1 (K), U3.1 (IN), U3.3 (EN)
unnamed: D13.2 (A), R24.1
unnamed: D14.2 (A), R25.1
unnamed: D15.2 (A), R26.1
unnamed: J4.3, RN1.8 (R1.2)
unnamed: J4.4, RN1.7 (R2.2)
unnamed: J4.5, RN1.6 (R3.2)
unnamed: J4.6, RN1.5 (R4.2)
unnamed: RN1.1 (R1.1), U8.14 (OUTA)
unnamed: RN1.2 (R2.1), U8.13 (OUTB)
unnamed: RN1.3 (R3.1), U8.12 (OUTC)
unnamed: RN1.4 (R4.1), U8.11 (OUTD)
unnamed: C11.1, U1.20 (AREF)
unnamed: C19.2, U3.5 (OUT), U8.16 (VCC2)
PWRpin: U1.32 (PD2), U8.6 (IND); also elsewhere on the board
RCMpol: U1.1 (PD3); also elsewhere on the board
RCMrx: U1.3 (PE0), U1.30 (PD0), U8.5 (INC); also elsewhere on the board
RxD: J11.1, U1.16 (PB4); also elsewhere on the board
TxD: J11.4, U1.15 (PB3); also elsewhere on the board
VCCio: D2.2 (A), J4.1
~CTS: J11.3, U1.17 (PB5); also elsewhere on the board
~RESET: J11.5, U1.29 (~RESET/PC6)
~RTS: U1.14 (PB2); also elsewhere on the board

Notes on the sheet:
Processor
Open: normal operation Close: ISP operation
ISP interface
(optional) mechanical purpose only
CPU
(optional) external Debug Signals

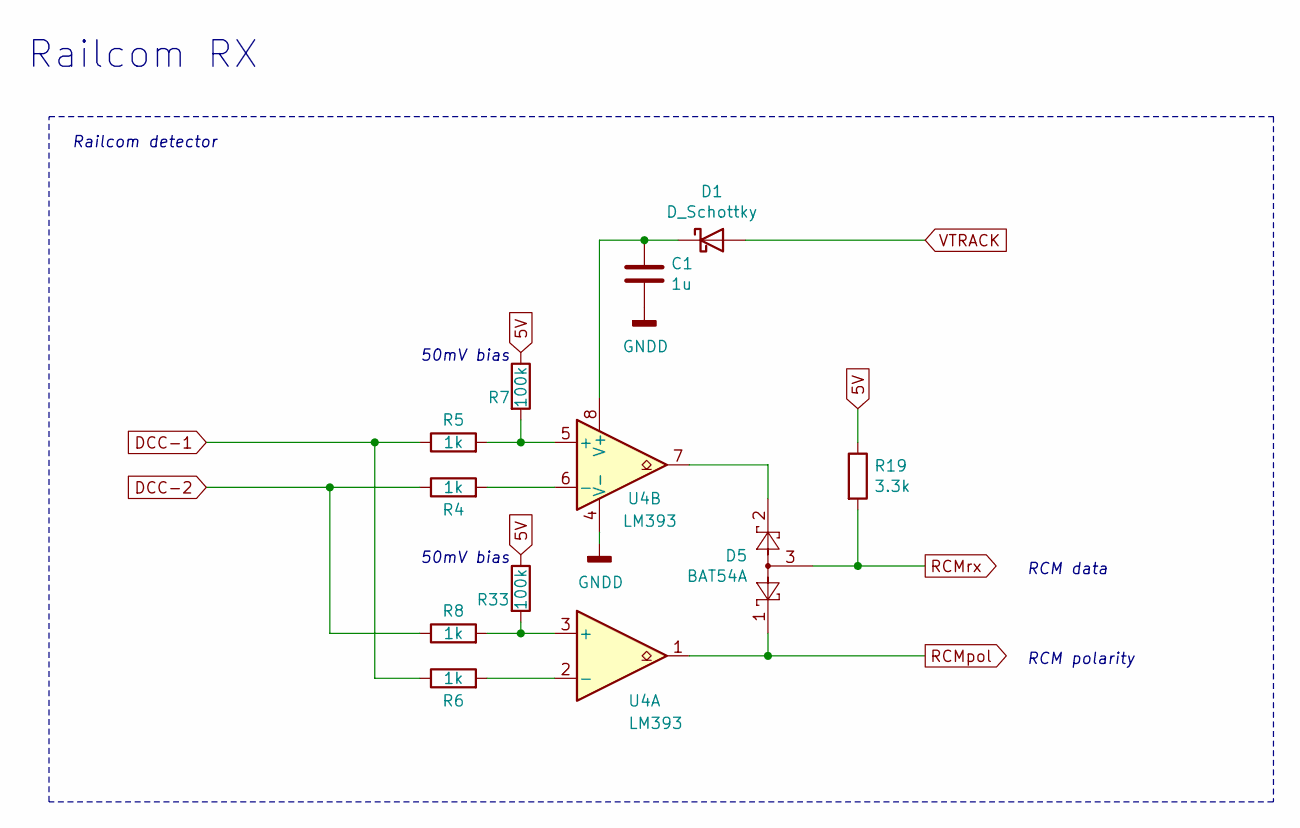
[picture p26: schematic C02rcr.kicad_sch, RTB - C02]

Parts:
C1: 1u; C_0603_1608Metric; LCSC Part # C15849
D1: D_Schottky; D_0603_1608Metric
D5: BAT54A; SOT-323_SC-70; LCSC Part # C78261
R4, R5, R6, R8: 1k; R_0603_1608Metric; LCSC Part # C21190
R7, R33: 100k; R_0603_1608Metric; LCSC Part # C25803
R19: 3.3k; R_0603_1608Metric; LCSC Part # C22978
U4: LM393; DFN-8_2x2mm_P0.5mm; LCSC Part # C2970927

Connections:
5V: R7.1, R19.1, R33.1; also elsewhere on the board
DCC-1: R5.1, R6.1; also elsewhere on the board
DCC-2: R4.1, R8.1; also elsewhere on the board
GNDD: C1.2, U4.4 (V-); also elsewhere on the board
unnamed: C1.1, D1.1 (K), U4.8 (V+)
unnamed: D5.2, U4.7
unnamed: R8.2, R33.2, U4.3 (+)
unnamed: R6.2, U4.2 (-)
unnamed: R5.2, R7.2, U4.5 (+)
unnamed: R4.2, U4.6 (-)
RCMpol: D5.1, U4.1; also elsewhere on the board
RCMrx: D5.3, R19.2; also elsewhere on the board
VTRACK: D1.2 (A); also elsewhere on the board

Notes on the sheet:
RCM polarity
50mV bias
Railcom detector
Railcom RX
RCM data

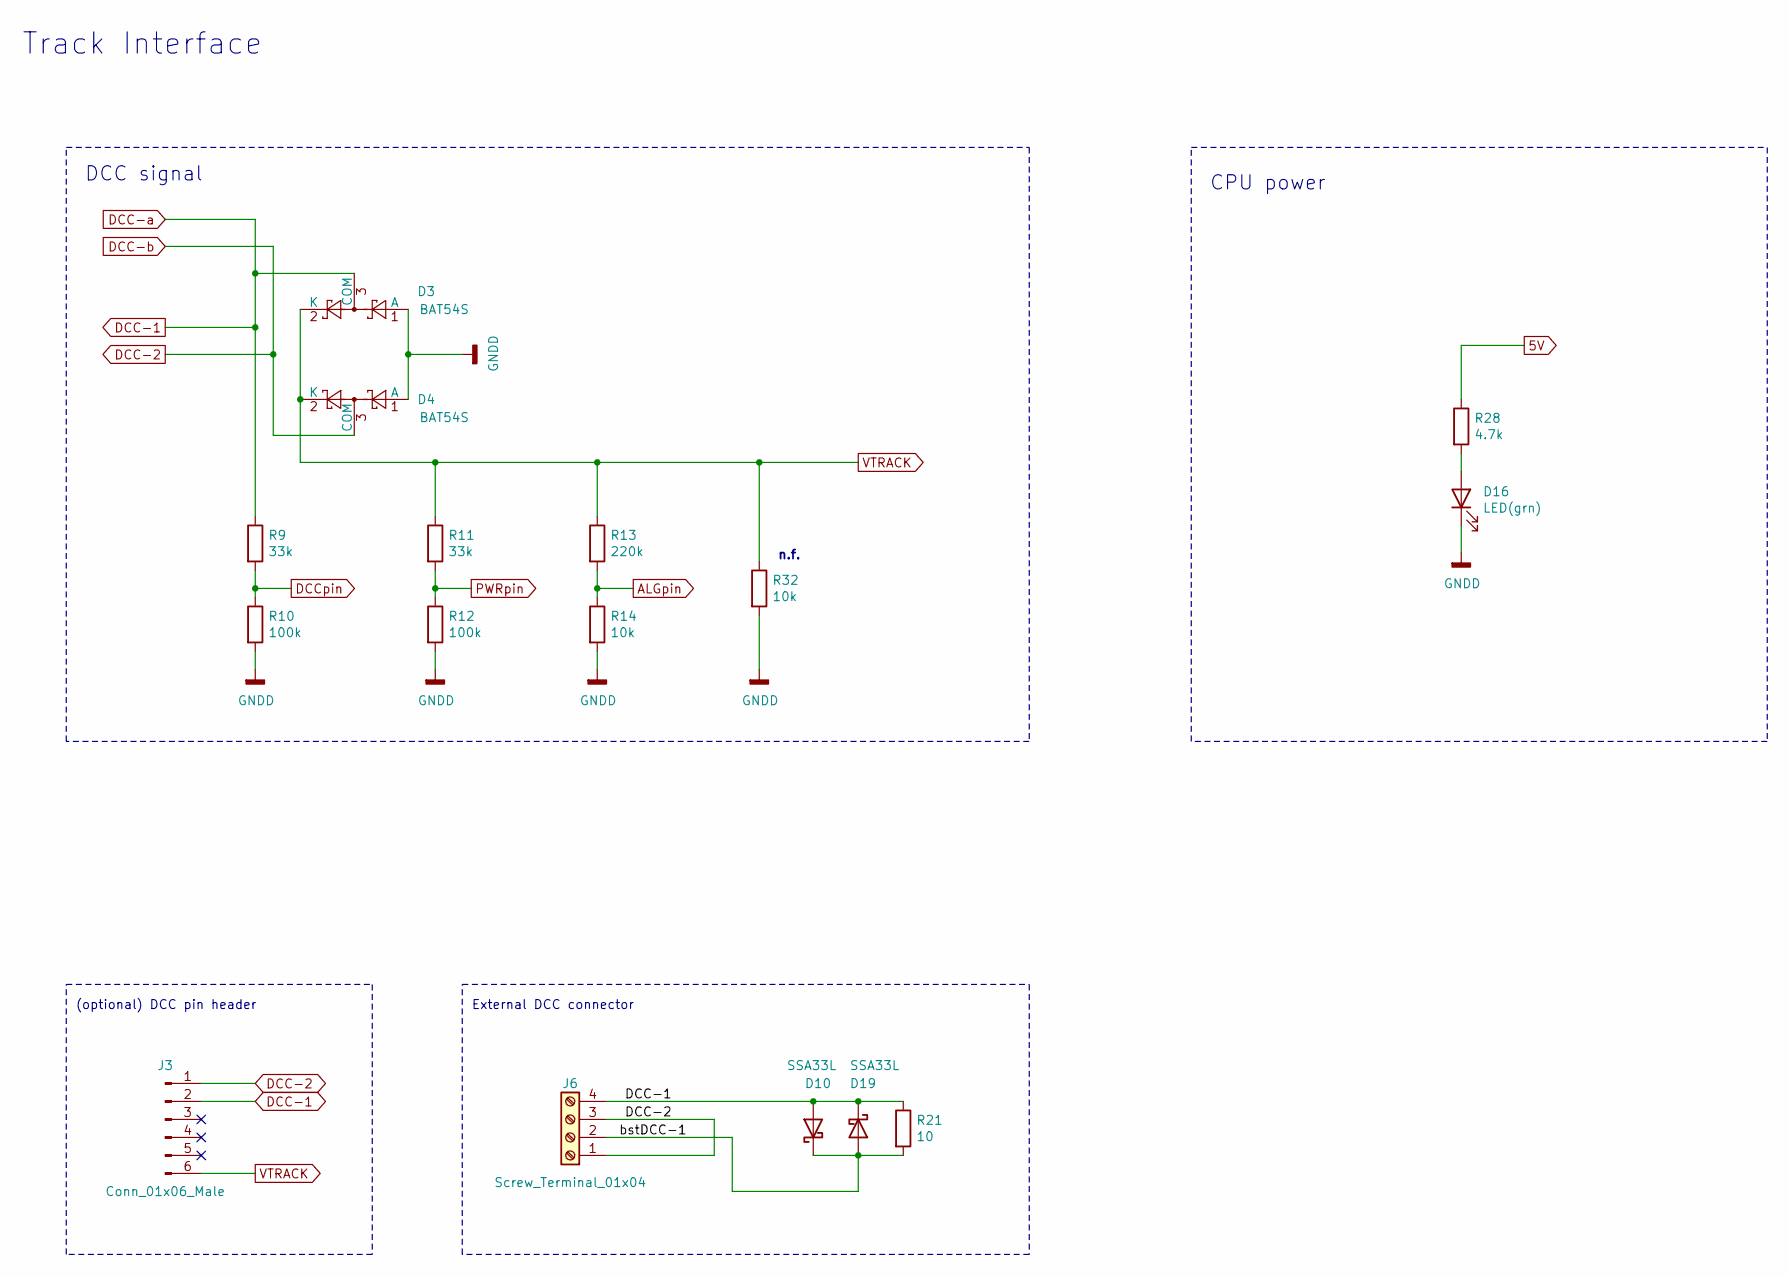
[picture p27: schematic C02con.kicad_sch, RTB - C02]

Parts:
D3, D4: BAT54S; SOT-323_SC-70; LCSC Part # C78606
D10, D19: SSA33L; D_SMA; LCSC Part # C435944
D16: LED(grn); LED_0603_1608Metric; LCSC Part # C2289
J3: Conn_01x06_Male; PinHeader_1x06_P2.54mm_Vertical
J6: Screw_Terminal_01x04; TerminalBlock_RND_205-00003_1x04_P5.00mm_Horizontal
R9, R11: 33k; R_0603_1608Metric; LCSC Part # C4216
R10, R12: 100k; R_0603_1608Metric; LCSC Part # C25803
R13: 220k; R_0603_1608Metric; LCSC Part # C22961
R14, R32: 10k; R_0603_1608Metric; LCSC Part # C25804
R21: 10; R_0603_1608Metric; LCSC Part # C22859
R28: 4.7k; R_0603_1608Metric; LCSC Part # C23162

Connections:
5V: R28.1; also elsewhere on the board
/Connectors/bstDCC-1: D10.1 (K), D19.2 (A), J6.2, R21.2
ALGpin: R13.2, R14.1; also elsewhere on the board
DCC-1: D3.3 (COM), D10.2 (A), D19.1 (K), J3.2, J6.4, R9.1, R21.1; also elsewhere on the board
DCC-2: D4.3 (COM), J3.1, J6.1, J6.3; also elsewhere on the board
DCCpin: R9.2, R10.1; also elsewhere on the board
GNDD: D3.1 (A), D4.1 (A), D16.1 (K), R10.2, R12.2, R14.2, R32.2; also elsewhere on the board
unnamed: D16.2 (A), R28.2
PWRpin: R11.2, R12.1; also elsewhere on the board
VTRACK: D3.2 (K), D4.2 (K), J3.6, R11.1, R13.1, R32.1; also elsewhere on the board

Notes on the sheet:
Track Interface
(optional) DCC pin header
CPU power
DCC signal
External DCC connector
n.f.

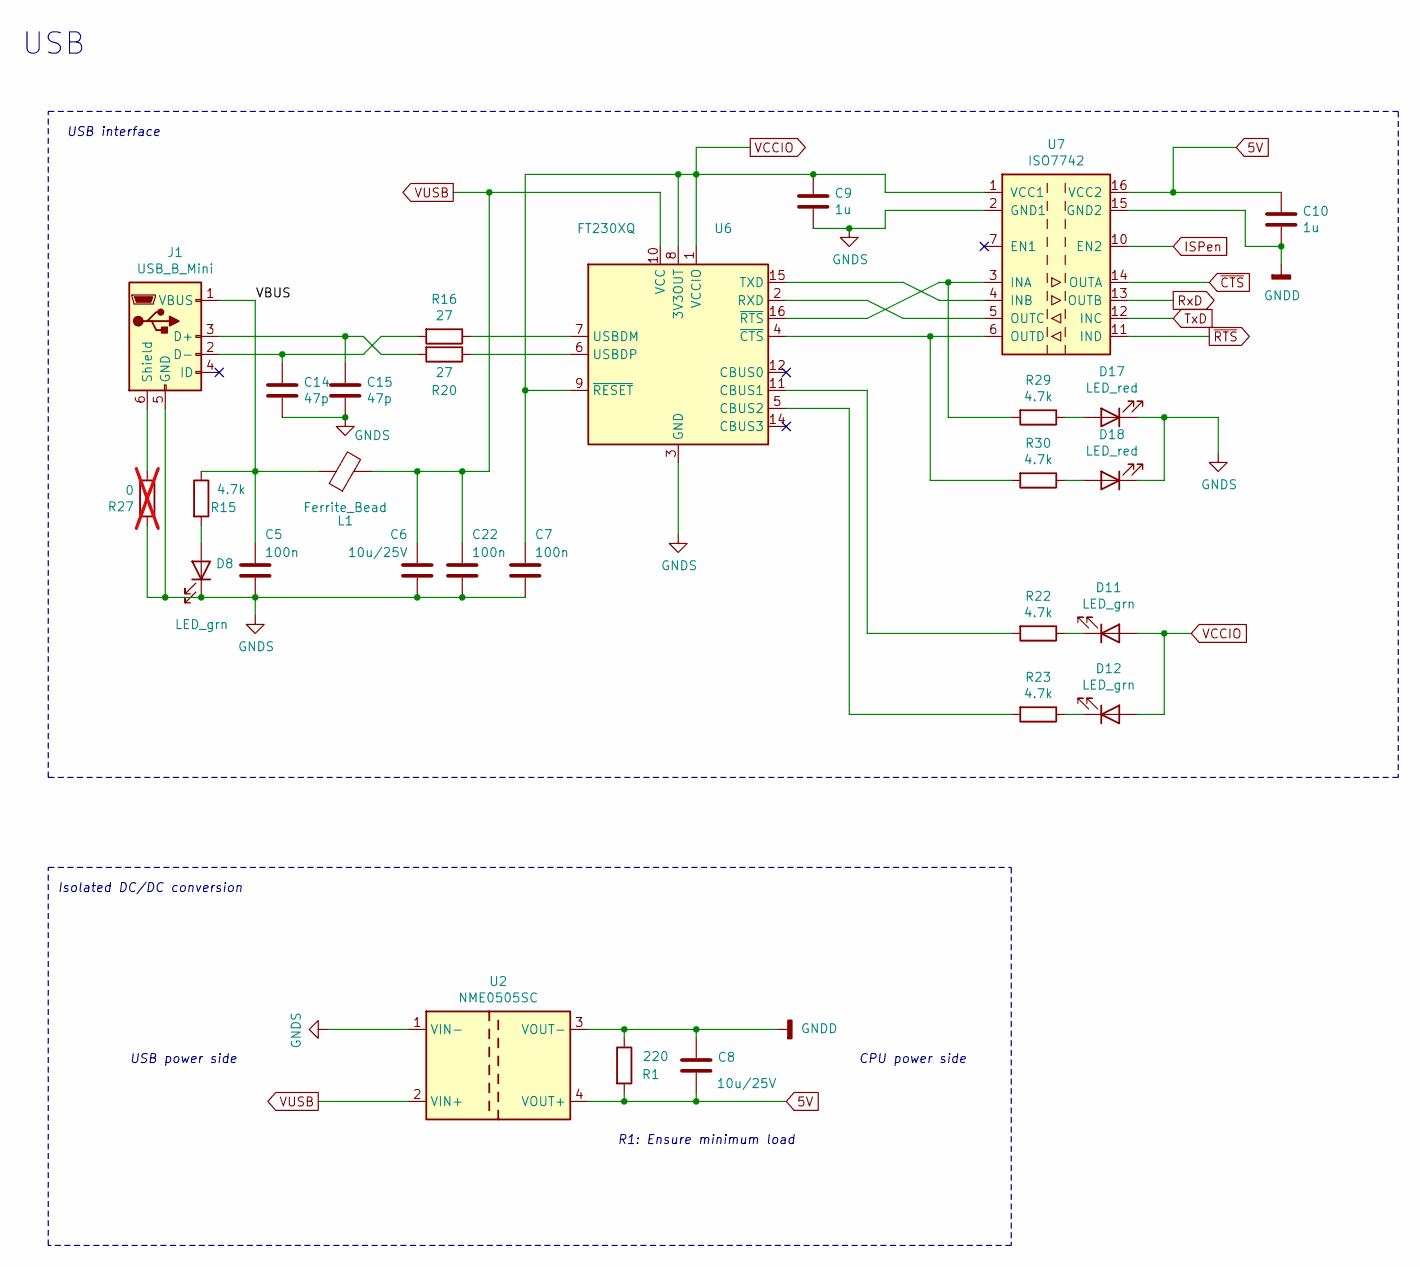
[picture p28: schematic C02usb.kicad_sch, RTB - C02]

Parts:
C5, C7, C22: 100n; C_0603_1608Metric; LCSC Part # C14663
C6, C8: 10u/25V; C_0603_1608Metric; LCSC Part # C96446
C9, C10: 1u; C_0603_1608Metric; LCSC Part # C15849
C14, C15: 47p; C_0603_1608Metric; LCSC Part # C1671
D8, D11, D12: LED_grn; LED_0603_1608Metric; LCSC Part # C2289
D17, D18: LED_red; LED_0603_1608Metric; LCSC Part # C125099
J1: USB_B_Mini; USB_Micro-B_Reichelt_BWM_SMD; LCSC Part # C2688795
L1: Ferrite_Bead; L_0805_2012Metric; LCSC Part # C1017
R1: 220; R_0805_2012Metric; LCSC Part # C17557
R15, R22, R23, R29, R30: 4.7k; R_0603_1608Metric; LCSC Part # C23162
R16, R20: 27; R_0603_1608Metric; LCSC Part # C23345
R27: 0; R_0603_1608Metric; LCSC Part # C21189; not fitted
U2: NME0505SC; DCDC-Conv_muRata_NMAxxxxSC
U6: FT230XQ; QFN-16-1EP_4x4mm_P0.65mm_EP2.5x2.5mm; LCSC Part # C3216402
U7: ISO7742; SSOP-16_3.9x4.9mm_P0.635mm; LCSC Part # C5216468

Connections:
5V: C8.1, C10.2, R1.2, U2.4 (VOUT+), U7.16 (VCC2); also elsewhere on the board
/USB/VBUS: C5.2, J1.1 (VBUS), L1.1, R15.1
GNDD: C8.2, C10.1, R1.1, U2.3 (VOUT-), U7.9 (GND2), U7.15 (GND2); also elsewhere on the board
GNDS: C5.1, C6.2, C7.1, C9.1, C14.1, C15.1, C22.1, D8.1 (K), D17.1 (K), D18.1 (K), J1.5 (GND), R27.2, U2.1 (VIN-), U6.3 (GND), U6.13 (GND), U6.17 (GND), U7.2 (GND1), U7.8 (GND1)
ISPen: U7.10 (EN2); also elsewhere on the board
unnamed: D8.2 (A), R15.2
unnamed: D11.1 (K), R22.1
unnamed: D12.1 (K), R23.1
unnamed: D17.2 (A), R29.1
unnamed: D18.2 (A), R30.1
unnamed: C15.2, J1.3 (D+), R20.2
unnamed: C14.2, J1.2 (D-), R16.2
unnamed: J1.6 (Shield), R27.1
unnamed: R22.2, U6.11 (CBUS1)
unnamed: R23.2, U6.5 (CBUS2)
unnamed: U6.2 (RXD), U7.5 (OUTC)
unnamed: U6.15 (TXD), U7.4 (INB)
unnamed: R16.1, U6.7 (USBDM)
unnamed: R20.1, U6.6 (USBDP)
unnamed: R30.2, U6.4 (~CTS), U7.6 (OUTD)
unnamed: R29.2, U6.16 (~RTS), U7.3 (INA)
RxD: U7.13 (OUTB); also elsewhere on the board
TxD: U7.12 (INC); also elsewhere on the board
VCCIO: C7.2, C9.2, D11.2 (A), D12.2 (A), U6.1 (VCCIO), U6.8 (3V3OUT), U6.9 (~RESET), U7.1 (VCC1)
VUSB: C6.1, C22.2, L1.2, U2.2 (VIN+), U6.10 (VCC)
~CTS: U7.14 (OUTA); also elsewhere on the board
~RTS: U7.11 (IND); also elsewhere on the board

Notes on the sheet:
Isolated DC/DC conversion
USB
R1: Ensure minimum load
USB interface
USB power side
CPU power side

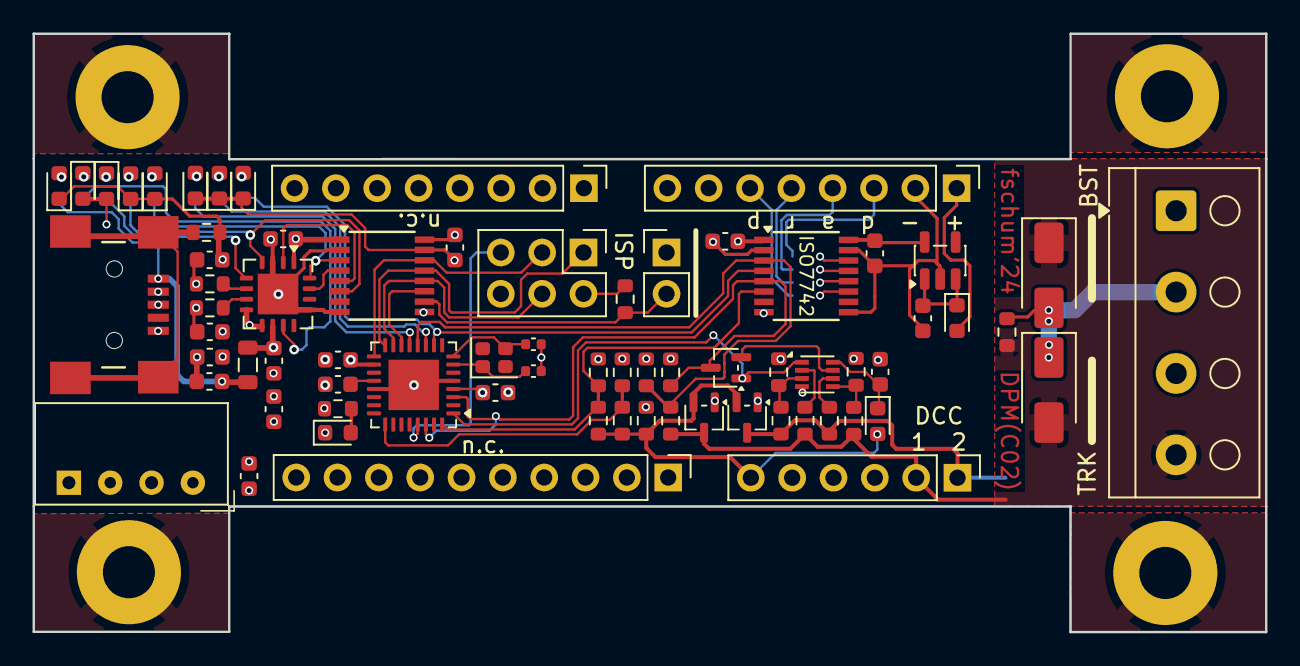
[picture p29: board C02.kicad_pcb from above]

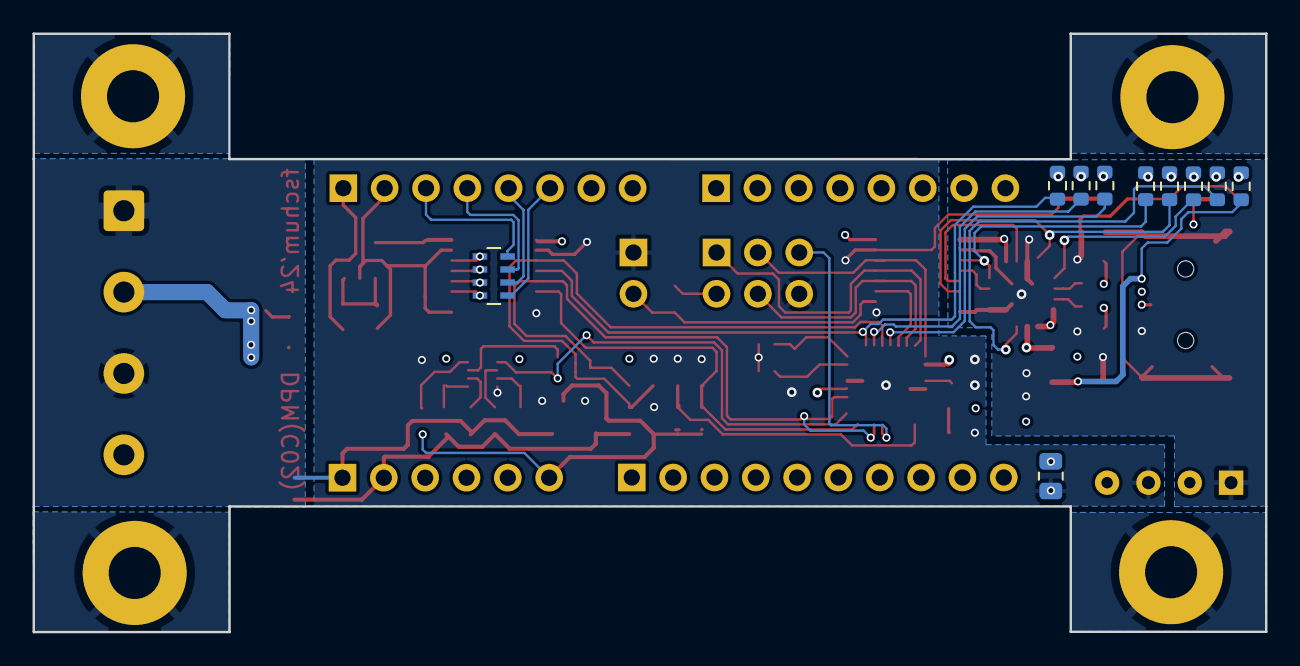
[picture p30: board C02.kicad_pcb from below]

Board: 4 copper layers, 75.7 x 36.8 mm, 85 parts (10 on the bottom side), 65 nets.

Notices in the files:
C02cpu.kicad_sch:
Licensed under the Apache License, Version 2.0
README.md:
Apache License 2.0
